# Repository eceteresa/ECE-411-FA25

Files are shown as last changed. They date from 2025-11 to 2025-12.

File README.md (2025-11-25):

# ECE 411 Fall 2025 Capstone
Hi hello! Welcome to our capstone. Please review software tools used and some tutorials for how to use said tools. :D

## Tools!

Here are the basic programs you'll need to have on your computer in order to interface with the projects:

- [VSCode](https://code.visualstudio.com/download): A helpful all-in-one programming IDE. Free!
      - You can install the [PlatformIO](https://docs.platformio.org/en/latest/integration/ide/vscode.html) extension and code .ino directly into the IDE!
- [Arduino IDE](https://www.arduino.cc/en/software/): If you would rather not use VSCode.
- Github: Not required, but _strongly_ recommended for ease of file sharing between machines. You can even work from your repo within VSCode using git bash!

### Github Onboarding Crash Course

[Github Setup](https://docs.github.com/en/get-started/git-basics/set-up-git)

[Using Git Graphical User Interface (GUI)](https://www.geeksforgeeks.org/git/working-on-git-for-gui/)

[Github markdown text cheat sheet](https://docs.github.com/en/get-started/writing-on-github/getting-started-with-writing-and-formatting-on-github/basic-writing-and-formatting-syntax)

[What are Git branches and why are they important](https://git-scm.com/book/en/v2/Git-Branching-Branches-in-a-Nutshell)

### Github Task Tracker

[Git Project Tracker Tutorial](https://docs.github.com/en/issues/planning-and-tracking-with-projects/learning-about-projects/quickstart-for-projects)
This tutorial should help you get familiar with how to use the task tracking board under "Projects" in the linked menu up above. There is a kanban template available, so it mimics what Trello can do almost exactly, if not better. The table layout was used so that it's a little easier to see who is assigned to what, and as I (Teresa) poke around with the task tracker it should be pretty intuitive to assign tasks and whatnot. And we don't have to worry about the Trello contributor limit for free accounts.

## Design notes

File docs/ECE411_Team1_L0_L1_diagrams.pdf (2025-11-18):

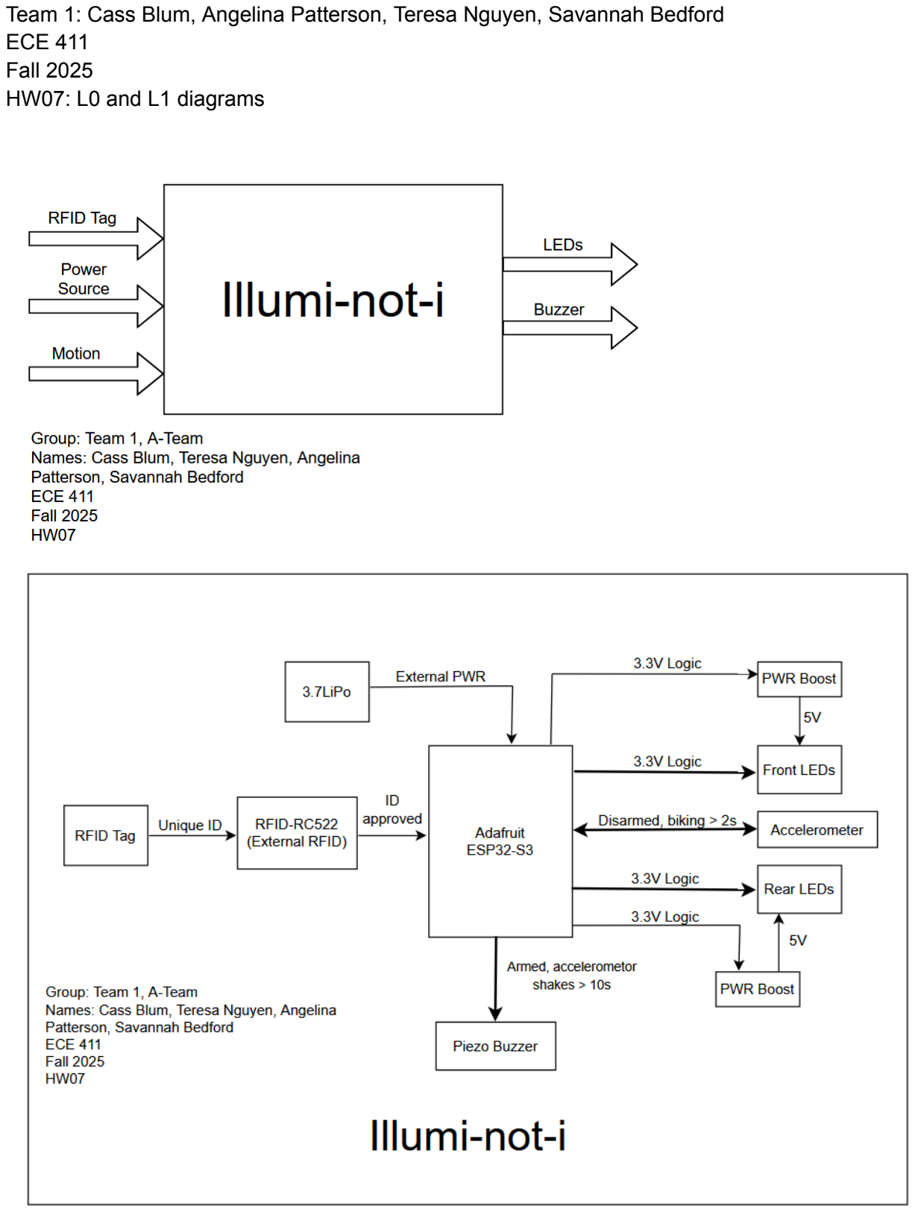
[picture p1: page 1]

Team 1: Cass Blum, Angelina Patterson, Teresa Nguyen, Savannah Bedford ECE 411
Fall 2025
HW07: L0 and L1 diagrams

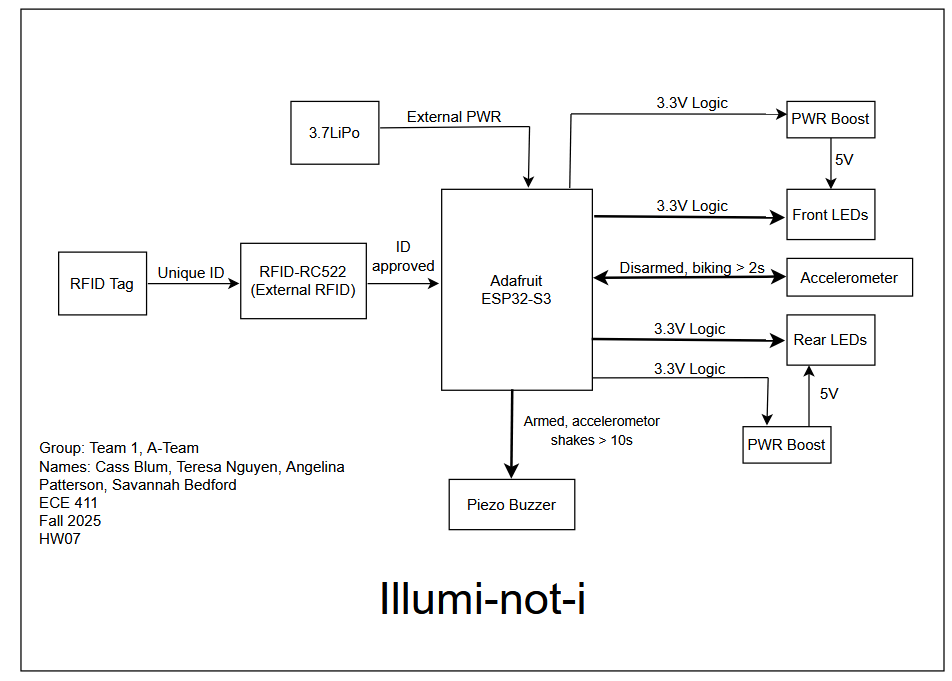
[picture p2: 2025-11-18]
docs/ECE411_Team1_HW07L1.png

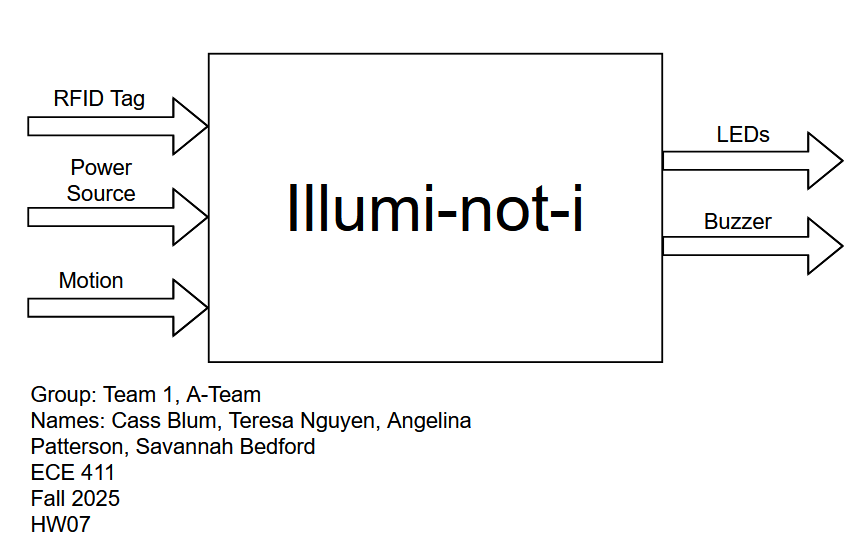
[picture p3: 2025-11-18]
docs/ECE411_Team1_HW07L0.png

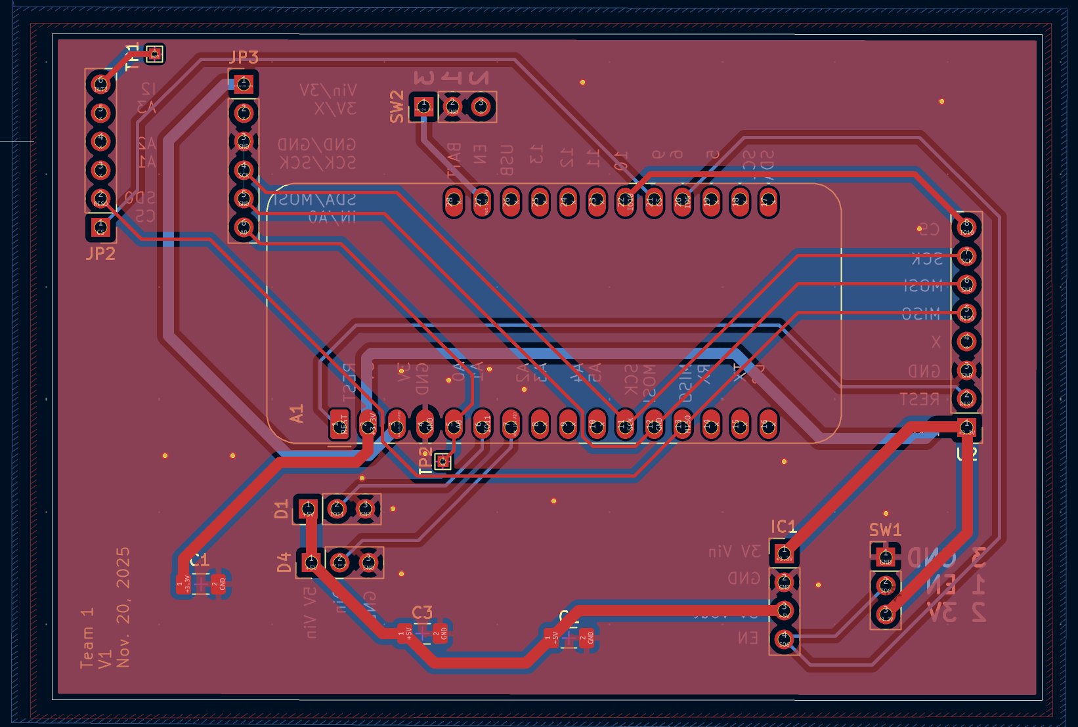
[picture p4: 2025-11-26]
docs/HW10_slideshow_images/PCB_ATeam.png

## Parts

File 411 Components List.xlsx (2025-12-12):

Component | Qty | Link | Item Price | Item Subtotal | Data Sheet | Input Voltage | Input Current | Tolerance | Notes | Subtotal | $274.13
3-axis accelerator | 4 | Adafruit (https://www.adafruit.com/product/2809) | $4.50 | $18.00 | Link (https://learn.adafruit.com/adafruit-lis3dh-triple-axis-accelerometer-breakout/downloads) | 3.3V - 5V | 130uA
WWZMDib RC522 RFID reader/writer | 4 | Amazon (https://www.amazon.com/WWZMDiB-2Pcs-RFID-Kit-Raspberry/dp/B0BDF6JT7M/ref=sr_1_3) | $6.99 | $27.96 | Link (https://www.handsontec.com/dataspecs/RC522.pdf) | 2.5V - 3.3V | 13 - 26mA |  | Tutorial (https://randomnerdtutorials.com/esp32-mfrc522-rfid-reader-arduino/) | MFRC522_digikey_datasheet (https://mm.digikey.com/Volume0/opasdata/d220001/medias/docus/5531/4411_CN0090%20other%20related%20document%20%281%29.pdf)
Adafruit Feather ESP32-S3 | 4 | Adafruit (https://learn.adafruit.com/adafruit-esp32-s3-feather/pinouts) | $17.50 | $70.00 | Link (https://learn.adafruit.com/adafruit-esp32-s3-feather) | 3.7V | 250mAh |  | Link has great overview
LiPo Battery for Feather (3.7V) | 4 | Adafruit (https://www.adafruit.com/product/3898) | $6.95 | $27.80 | Link (https://cdn-shop.adafruit.com/product-files/3898/3898_specsheet_LP801735_400mAh_3.7V_20161129.pdf) | 3.7V | 400mAh
Neopixel LED strips | 30 | Adafruit (https://www.adafruit.com/product/2552) | $2.50 | $75.00 | Link (https://cdn-shop.adafruit.com/product-files/2552/Datasheet.pdf) | 5V | 60mA |  | Needs to be powered with 5V, can handle 3.3V logic
TPS61023 Boost Converter | 5 | Adafruit (https://www.adafruit.com/product/4654) | $3.95 | $19.75 | TPS61023 chip (https://www.ti.com/product/TPS61023) | 2V - 5V -> 5V | varies |  | Boost Converter Datasheet (https://cdn-shop.adafruit.com/product-files/2552/Datasheet.pdf)
Jumper Wires | 2 | Adafruit (https://www.adafruit.com/product/1957) | $1.95 | $3.90 | n/a |  |  |  | bundle of 20
Small Breadboard | 1 | Amazon (https://www.amazon.com/DEYUE-breadboard-Set-Prototype-Board/dp/B07LFD4LT6?s=electronics) | $6.48 | $6.48 | n/a |  |  |  | pack of 6
switch | 6 | Adafruit (https://www.adafruit.com/product/805) | $0.95 | $5.70 | - | - | - | -
single row female pin headers | 3 | EPL | $1.00 | $3.00
22AWG stranded wire | 18 | EPL | $0.25 | $4.50
330 ohm resistors | 4 | EPL | $0.10 | $0.40
passive buzzers | 4 | EPL | $0.50 | $2.00
FDM Print (Protoboard Housing) | 1 | EPL | $9.64 | $9.64 | n/a | n/a | n/a | n/a | housing for protoboard

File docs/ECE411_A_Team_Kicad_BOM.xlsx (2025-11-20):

Bill Of Materials for: Team 1 - A-Team
Last modified: 11/16/2025
PCB version: 6
BOM revision: 4
Qty | Reference | Description | MF | Part number | Cost Ea. | Cost Total
1 | C1 | 10 µF ±5% 25V Ceramic Capacitor X7R 1206 (3216 Metric) | Digikey | 399-15735-2-ND | $1.39 | $1.39
2 | C2,C3 | Multilayer Ceramic Capacitors MLCC - SMD/SMT 10V 22uF X7R 1206 20 % | Mouser | 581-KGM31AR71A226MU | $0.54 | $1.08
2 | D1,D2 | RGB LED with integrated controller, 2.0 x 2.0 mm, 12 mA | Adafruit | 2552 | $3.00 | $3.00
1 | IC1 | mini-booster! Input 2-5VDC on one side | Adafruit | 4654 | $3.95 | $3.95
1 | A1 | RF Module, ESP32-S3 SoC, Wi-Fi 802.11b/g/n, Bluetooth, BLE, 32-bit, 3.3V, onboard antenna, SMD | Adafruit | 5477 | $17.50 | $17.50
1 | U2 | 3-Axis Accelerometer, 2/4/8/16g range, I2C/SPI interface, LGA-16 | Adafruit | 2809 | $4.50 | $4.50
1 | U3 | RFID RC522 Reader IC Card Module Tags SPI Interface Read and Write | YKS | CEG006900 | $6.99 | $6.99
1 | SW1 | Switch slide, single pole double throw | Adafruit | 805 | $0.95 | $0.95
VERSION INFO
Rev | Date
1 | 2025-11-07
2 | 2025-11-10
3 | 2025-11-11
3 | 2025-11-16
4 | 2025-11-20

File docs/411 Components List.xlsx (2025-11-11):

Component | Qty | Link | Item Subtotal | Data Sheet | Input Voltage | Input Current | Notes | Subtotal | $185.76
3-axis accelerator | 4 | Link (https://www.adafruit.com/product/2809) | $18.00 | Link (https://learn.adafruit.com/adafruit-lis3dh-triple-axis-accelerometer-breakout/downloads) | 3.3V - 5V | 130uA
WWZMDib RC522 RFID reader/writer | 4 | Link (https://www.amazon.com/WWZMDiB-2Pcs-RFID-Kit-Raspberry/dp/B0BDF6JT7M/ref=sr_1_3) | $27.96 | Link (https://www.handsontec.com/dataspecs/RC522.pdf) | 2.5V - 3.3V | 13 - 26mA | Tutorial (https://randomnerdtutorials.com/esp32-mfrc522-rfid-reader-arduino/) | MFRC522_digikey_datasheet (https://mm.digikey.com/Volume0/opasdata/d220001/medias/docus/5531/4411_CN0090%20other%20related%20document%20%281%29.pdf)
Adafruit Feather ESP32-S3 | 4 | Adafruit (https://www.adafruit.com/product/5000) | $27.96 | Link (https://learn.adafruit.com/adafruit-esp32-s3-feather) | 3.7V | 250mAh | Link has great overview
LiPo Battery for Feather (3.7V) | 4 | Link (https://www.adafruit.com/product/3898) | $27.96 | Link (https://cdn-shop.adafruit.com/product-files/3898/3898_specsheet_LP801735_400mAh_3.7V_20161129.pdf) | 3.7V | 400mAh
Neopixel LED strips | 8 | Adafruit (https://www.adafruit.com/product/2552) | $55.92
TPS61023 Boost Converter | 4 | Adafruit (https://www.adafruit.com/product/4654) | $27.96 | TPS61023 chip (https://www.ti.com/product/TPS61023) | 2V - 5V -> 5V | varies | Boost Converter Datasheet (https://cdn-shop.adafruit.com/product-files/2552/Datasheet.pdf)

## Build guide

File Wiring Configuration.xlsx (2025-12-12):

Component | ESP32 | LIS3DH | RFID | LED 1 | LED 2 | TPS | PIEZO
Pin Number | 5 |  |  | Din
 | 6 |  |  |  | Din
 | 9 | CS
 | 10 |  | SDA
 | 11 |  |  |  |  |  | Terminal 1
 | 5 to LED
 | RST |  | RST
 | 3.3V | Vin | 3.3V |  |  | Vin
 | GND | GND | GND | GND | GND | GND | GND
 | A0 | INT
 | SCK | SCL | SCK
 | MO | SDA | MOSI
 | MI | SDO | MI
 |  |  |  | 5V | 5V | 5V

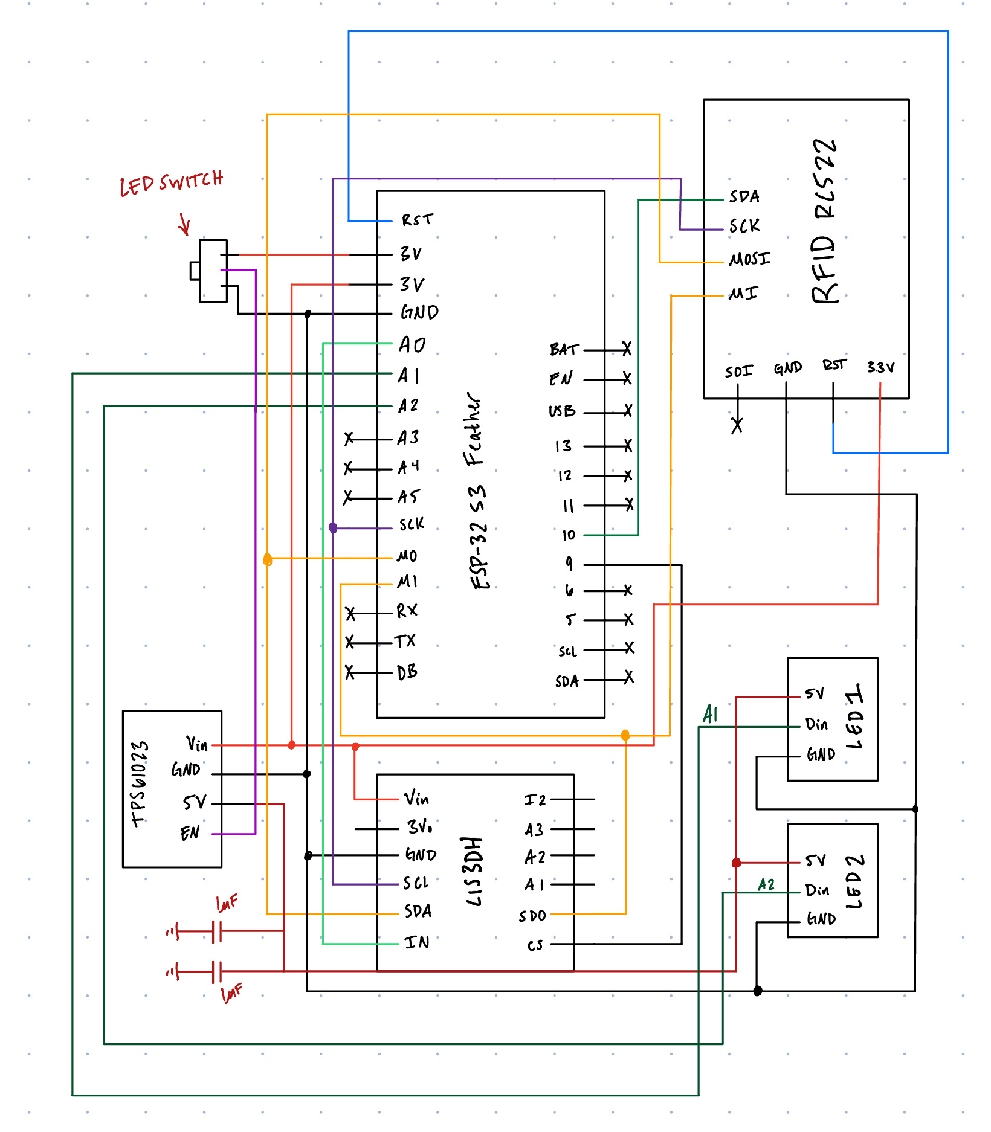
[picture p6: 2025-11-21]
docs/411wiringDiagram_rev2.png

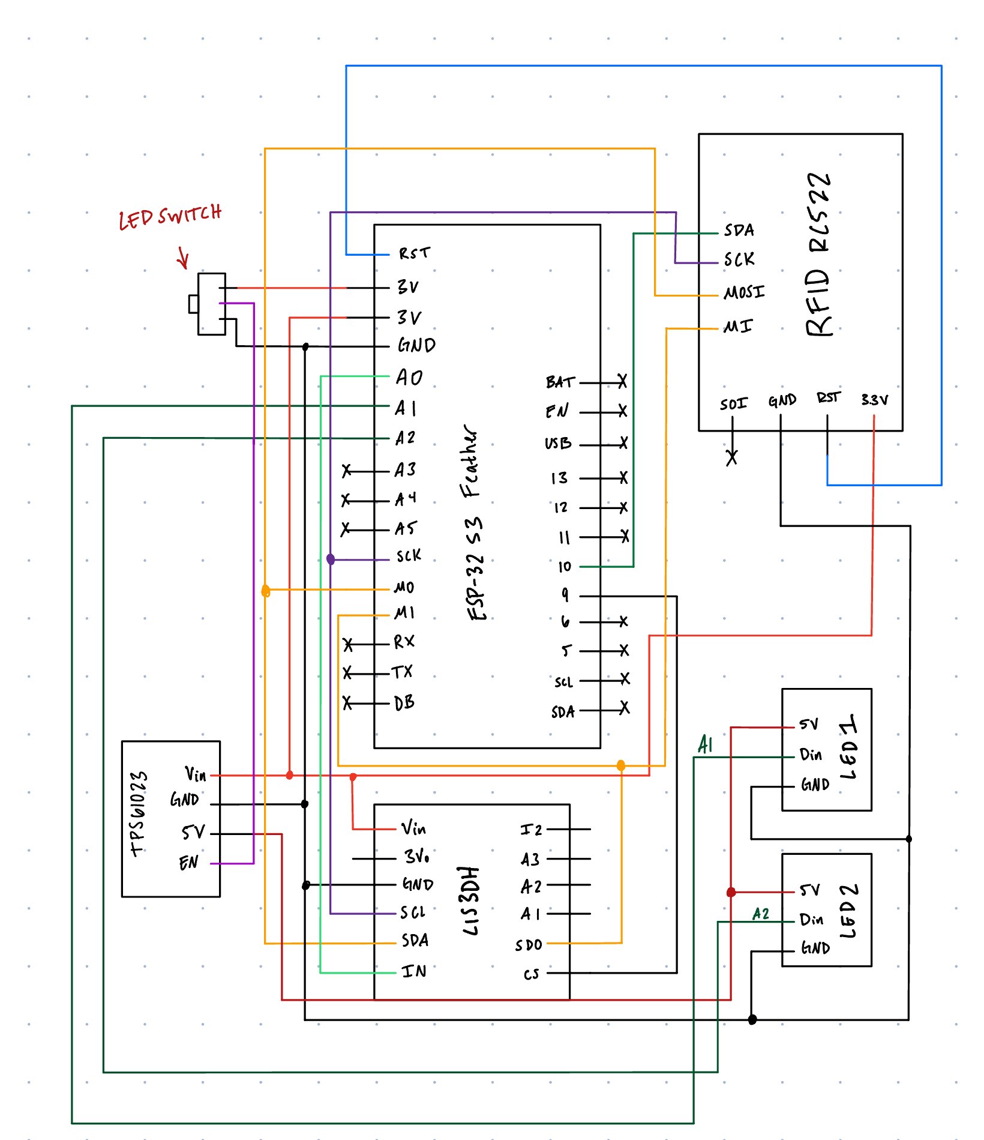
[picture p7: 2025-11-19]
docs/411wiringDiagram.jpg

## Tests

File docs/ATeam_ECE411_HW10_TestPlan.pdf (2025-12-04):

Test Case

Test Author: A-Team (Cass Blum, Teresa Nguyen, Savannah Bedford, Angelina Patterson)
Test Case Name: | Illumi-not-i full system test | Test ID #: | Illumi-not-i-01
Description: | Testing our subsystems that feature the RFID arming and disarming of the alarm system, checking the LiPo battery, along with the LEDs when implemented, and ensuring the accelerometer detects motion and the boost converter powers up the LED strips. | Type: | □ white box □ black box □ __Both______

Tester Information
| Name of Tester: | | Date:
| HW/SW Version: | 1.0 | Time:
| Setup: | Ensure the system's features are fully integrated.
S T E P | Action | Expected Result | P A S S | F A I L | N / A | Comments
1 | 3.7V LiPol battery | -The ESP32-S3 powers on along with the LED strips.
2 | Accelerometer | - Timed shaker testing: - >10s, serial monitor reads “Stealing!” - <10s, serial monitor reads, “10s alarm timer set…” - >2s, serial monitor reads, “Biking!” - <2s, serial monitor does nothing - >3s, serial monitor reads, “Stopped!” - <3s, serial monitor reads, “Biking!”
3 | RFID Tag | -RFID is tapped, it arms the system. - RFID badge is tapped after arming, it DISARMS the system.
4 | Piezo Buzzer | Based on the accelerometer motion: - On when shaken >10s. - Off when shaken <10s. Timer resets and continues countdown.
5 | Boost converter | -Converts 3.7V to 5V. - Powers on the LED strips.
2025-11-28 | Page 1 of 4

6 | LED strips | -LED strips are on. - The switch is flipped, and the LEDs light up. - The brightness of the LEDs is adjusted.
| Overall test result:

Matrix Test

Test Author: A-Team

Test Case Name: | LED strip behavior and power test | Test ID #: | LED-01
Description: | Verification of the LED strips lights up based on the input voltage of the boost converter. To demonstrate how the power system and LEDs behave under different supply conditions. | Type: | □ white box □ black box □ _____________

Tester Information

| Name of Tester: | | Date:
| HW/SW Version: | 1.0 | Time:
| Setup: | Isolate the LED system and use a power supply to test the input with different number values 0 - 255 based on NeoPixel’s RGB value settings
T E S T | INPUTS | EXPECTED OUTPUTS | P A S S | F A I L | N / A | Comments
1 | 255 | LEDs at max brightness.
2 | 175 | LEDs slightly dim from max brightness.
3 | 90 | LEDs start to dim or flicker
4 | 50 | LEDs are flickering or are about to turn off.

5 | 0 | LEDs should not turn on.
| Overall test result:

Test Author: A-Team

Test Case Name: | RFID badge test | Test ID #: | RFID-01
Description: | Verification of RFID badge functionality. When the RFID badge is tapped it should be able to read the dedicated hex ID, as well as determine if the Illumi-not-i system is armed or disarmed. | Type: | □ white box □ black box □ _____________

Tester Information

| Name of Tester: | Teresa Nguyen | Date: | 05-12-2025
| HW/SW Version: | 1.0 | Time: | Is fake
| Setup: | Testing RFID functionality
T E S T | INPUTS | EXPECTED OUTPUTS | P A S S | F A I L | N / A | Comments
1 | RFID ID recognition | Serial Monitor gives approval message if correct badge, rejection message if incorrect badge.
2 | RFID arming the system | If Illumi-not-i is ARMED, serial monitor should read “locked!” when RFID badge taps. If time, add RFID lighting system to reflect behavior (flash red? orange?)

3 | RFID disarming the system | If Illumi-not-i is DISARMED, serial monitor should read “unlocked!” when RFID badge taps. If time, add RFID lighting system to reflect behavior (flash green? purple?)
| Overall test result:

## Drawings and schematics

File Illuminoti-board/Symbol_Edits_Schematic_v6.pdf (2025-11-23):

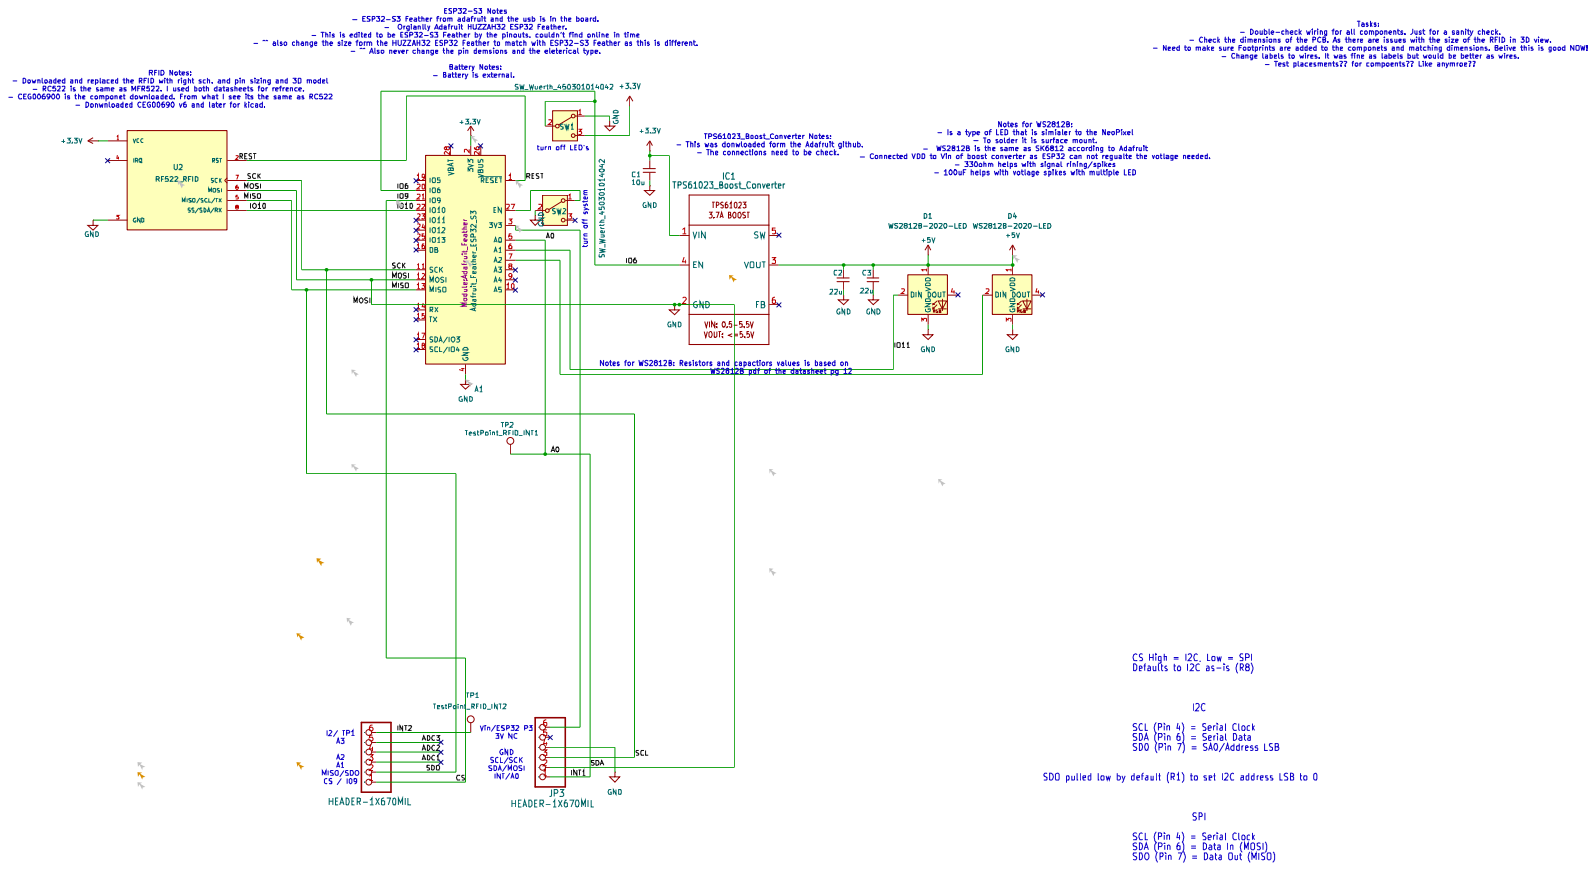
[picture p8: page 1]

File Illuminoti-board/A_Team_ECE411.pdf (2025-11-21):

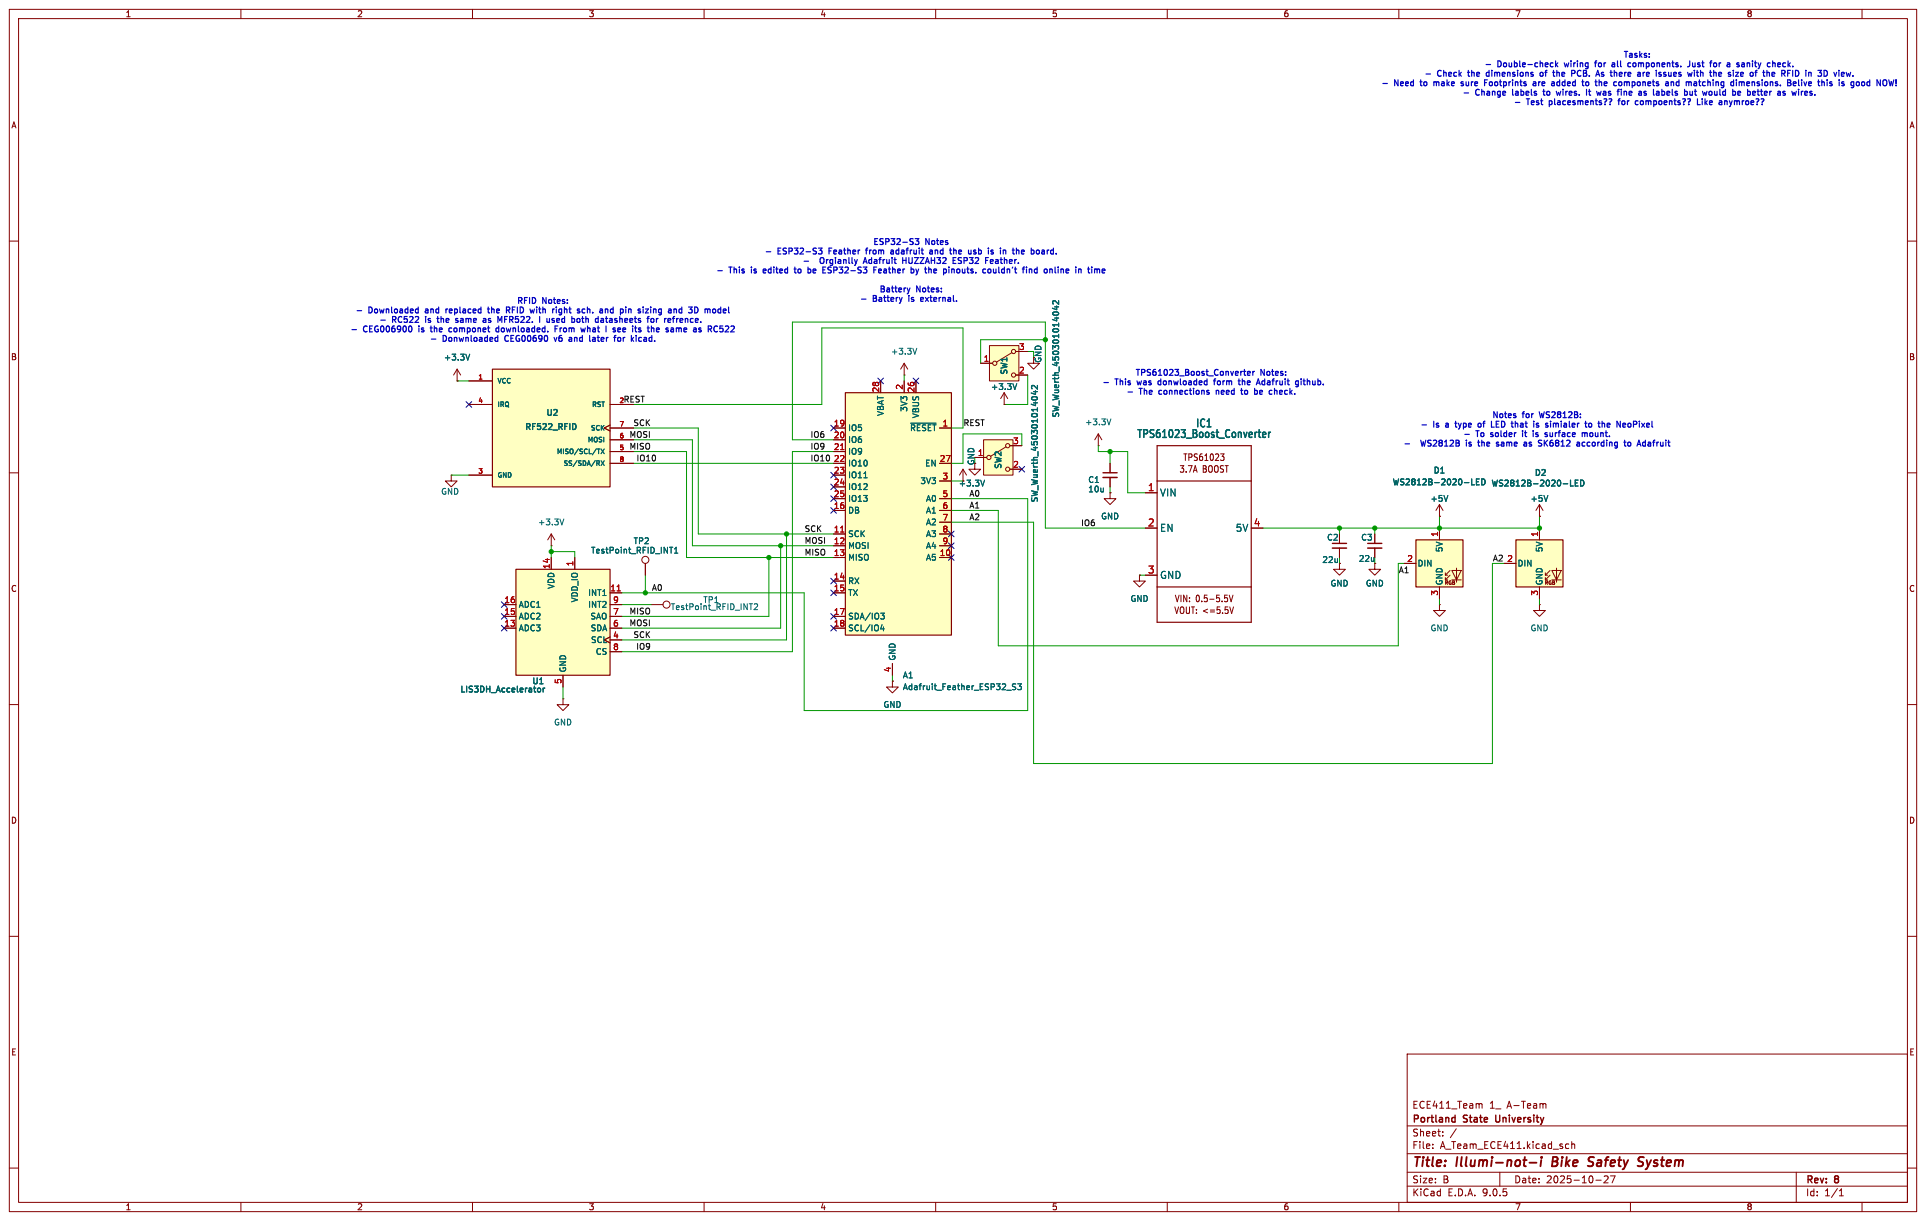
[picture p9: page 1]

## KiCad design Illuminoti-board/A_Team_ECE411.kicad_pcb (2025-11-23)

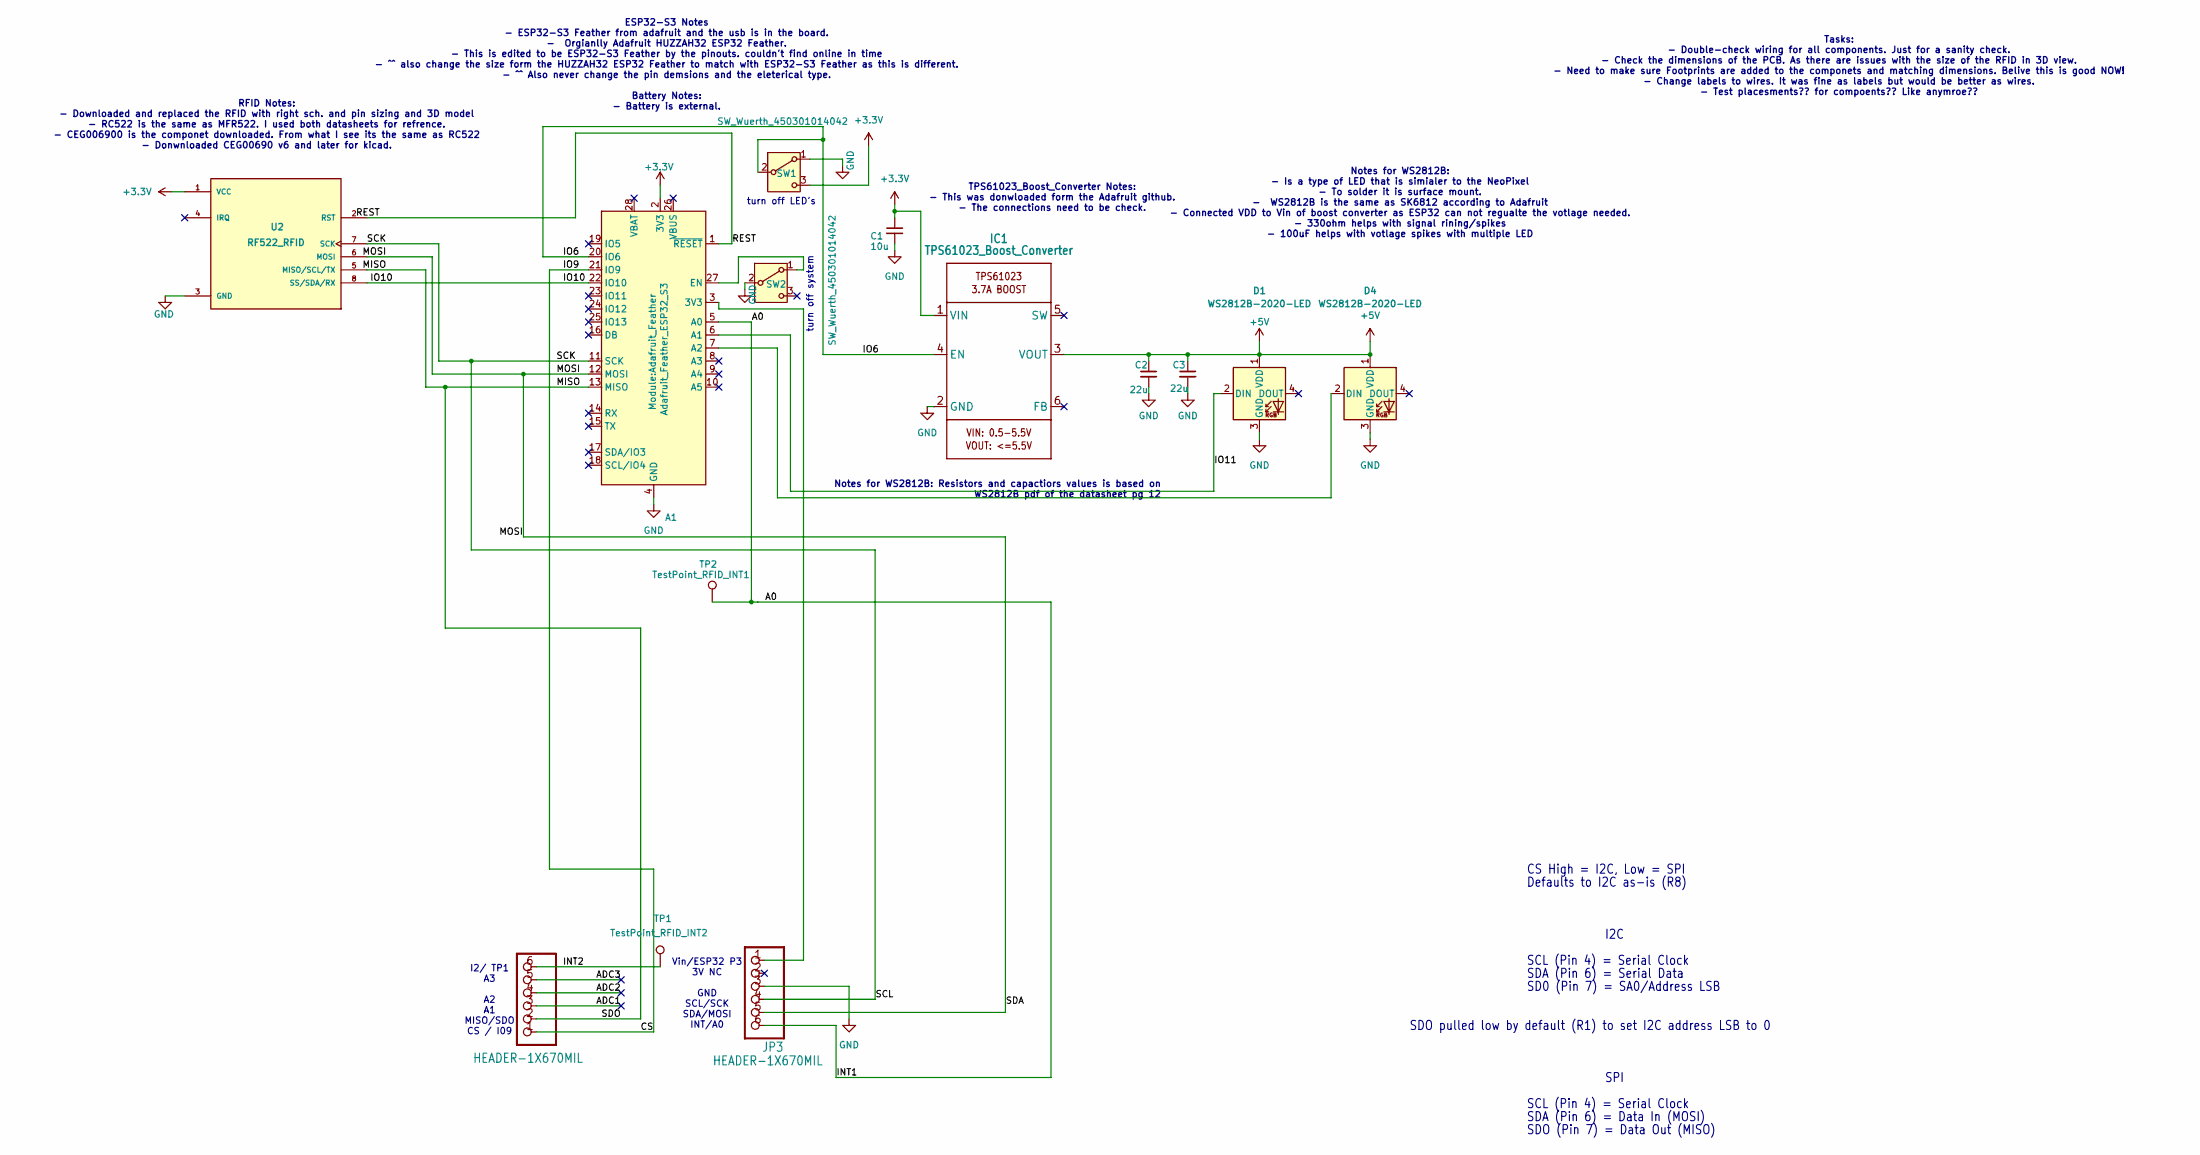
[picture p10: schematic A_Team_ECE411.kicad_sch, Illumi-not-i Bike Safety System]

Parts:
A1: Adafruit_Feather_ESP32_S3; Adafruit_Feather
C1: 10u; C_1206_3216Metric_Pad1.33x1.80mm_HandSolder; Part number 399-15735-2-ND
C2, C3: 22u; C_1206_3216Metric_Pad1.33x1.80mm_HandSolder; Part number 581-KGM31AR71A226MU
D1, D4: WS2812B-2020-LED; PinHeader_1x03_P2.54mm_Vertical; Part number 2552
IC1: TPS61023_Boost_Converter; PinHeader_1x04_P2.54mm_Vertical; Part number 4654
JP2, JP3: HEADER-1X670MIL; PinHeader_1x06_P2.54mm_Vertical
SW1, SW2: SW_Wuerth_450301014042; PinHeader_1x03_P2.54mm_Vertical
TP1: TestPoint_RFID_INT2; TestPoint_THTPad_1.0x1.0mm_Drill0.5mm
TP2: TestPoint_RFID_INT1; TestPoint_THTPad_1.0x1.0mm_Drill0.5mm
U2: RF522_RFID; PinHeader_1x08_P2.54mm_Vertical; PARTREV 12 June 2019

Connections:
+3.3V: A1.2 (3V3), C1.1, IC1.1 (VIN), SW1.3 (3V), U2.1 (VCC)
+5V: C2.1, C3.1, D1.1 (VDD), D4.1 (VDD), IC1.3 (VOUT)
/A0: A1.5 (A0), JP3.6, TP2.1
/ADC1: JP2.3
/ADC2: JP2.4
/ADC3: JP2.5
/CS: A1.21 (IO9), JP2.1
/INT2: JP2.6, TP1.1
/IO6: A1.20 (IO6), IC1.4 (EN), SW1.2 (B)
/IO10: A1.22 (IO10), U2.8 (SS/SDA/RX)
/IO11: A1.6 (A1), D1.2 (DIN)
/MISO: A1.13 (MISO), JP2.2, U2.5 (MISO/SCL/TX)
/MOSI: A1.12 (MOSI), JP3.5, U2.6 (MOSI)
/REST: A1.1 (~RESET), U2.2 (RST)
/SCK: A1.11 (SCK), JP3.4, U2.7 (SCK)
GND: A1.4 (GND), C1.2, C2.2, C3.2, D1.3 (GND), D4.3 (GND), IC1.2 (GND), JP3.3, SW1.1 (GND), SW2.2 (B), U2.3 (GND)
unnamed: A1.3 (3V3), JP3.1
unnamed: A1.7 (A2), D4.2 (DIN)
unnamed: A1.27 (EN), SW2.1 (A)

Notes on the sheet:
Tasks: - Double-check wiring for all components. Just for a sanity check. - Check the dimensions of the PCB. As there are issues with the size of the RFID in 3D view. - Need to make sure Footprints are added to the componets and matching dimensions. Belive this is good NOW! - Change labels to wires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
SDO (Pin 7) = Data Out (MISO)
SDA (Pin 6) = Data In (MOSI)
SCL (Pin 4) = Serial Clock
I2/ TP1 A3 A2 A1 MISO/SDO CS / I09
SPI
SD0 (Pin 7) = SA0/Address LSB
ESP32-S3 Notes - ESP32-S3 Feather from adafruit and the usb is in the board. - Orgianlly Adafruit HUZZAH32 ESP32 Feather. - This is edited to be ESP32-S3 Feather by the pinouts. couldn't find online in time - ^^ also change the size form the HUZZAH32 ESP32 Feather to match with ESP32-S3 Feather as 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
SDO pulled low by default (R1) to set I2C address LSB to 0
TPS61023_Boost_Converter Notes: - This was donwloaded form the Adafruit github. - The connections need to be check.
Notes for WS2812B: - Is a type of LED that is simialer to the NeoPixel - To solder it is surface mount. - WS2812B is the same as SK6812 according to Adafruit - Connected VDD to Vin of boost converter as ESP32 can not regualte the votlage needed. - 330ohm helps with signal rining/spikes - 100uF help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
Vin/ESP32 P3 3V NC GND SCL/SCK SDA/MOSI INT/A0
Defaults to I2C as-is (R8)
SDA (Pin 6) = Serial Data
turn off LED's
turn off system
Notes for WS2812B: Resistors and capactiors values is based on WS2812B pdf of the datasheet pg 12
CS High = I2C, Low = SPI
RFID Notes: - Downloaded and replaced the RFID with right sch. and pin sizing and 3D model - RC522 is the same as MFR522. I used both datasheets for refrence. - CEG006900 is the componet downloaded. From what I see its the same as RC522 - Donwnloaded CEG00690 v6 and later for kicad.
I2C

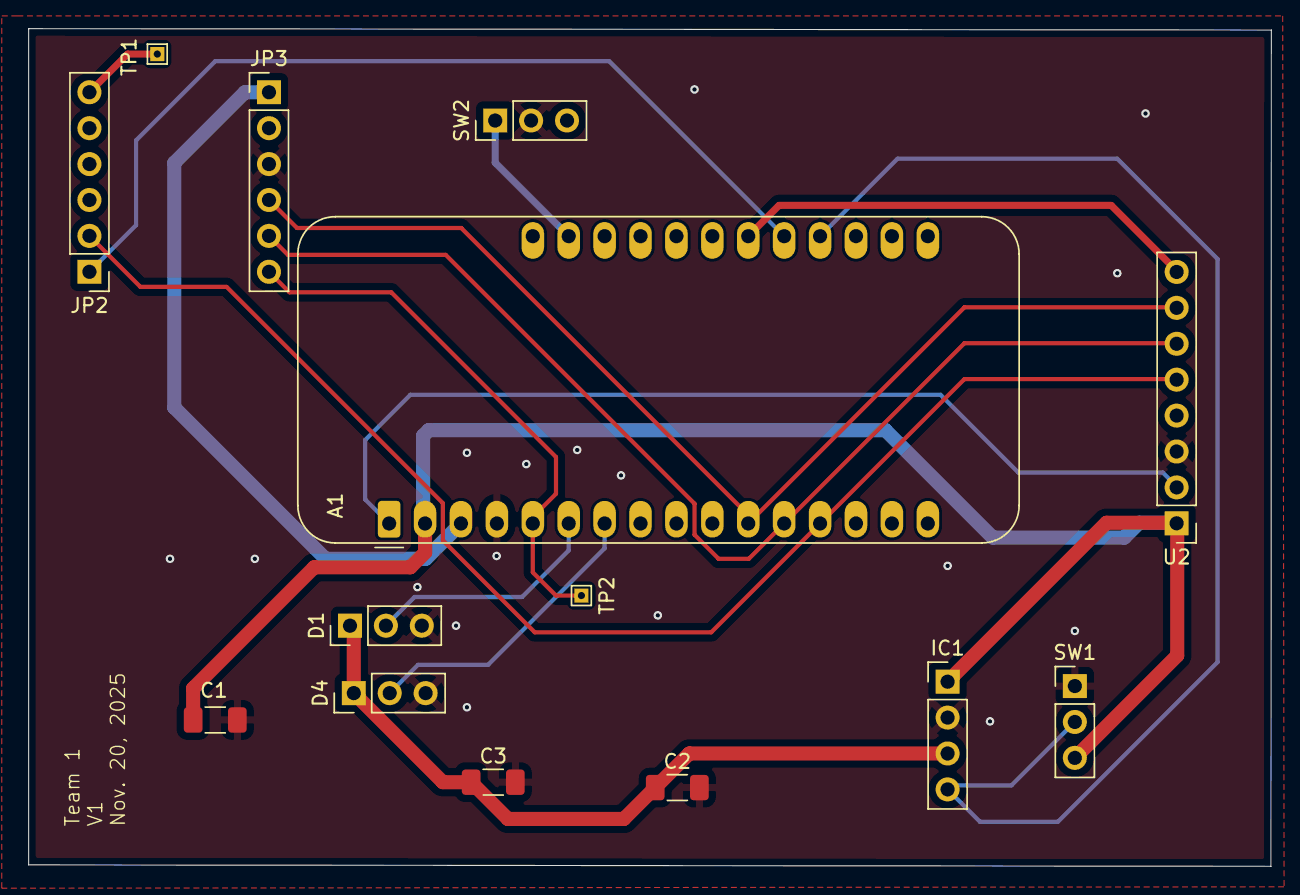
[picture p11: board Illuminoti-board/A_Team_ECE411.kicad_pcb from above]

Board: 2 copper layers, 87.9 x 59.2 mm, 14 parts (0 on the bottom side), 16 nets.

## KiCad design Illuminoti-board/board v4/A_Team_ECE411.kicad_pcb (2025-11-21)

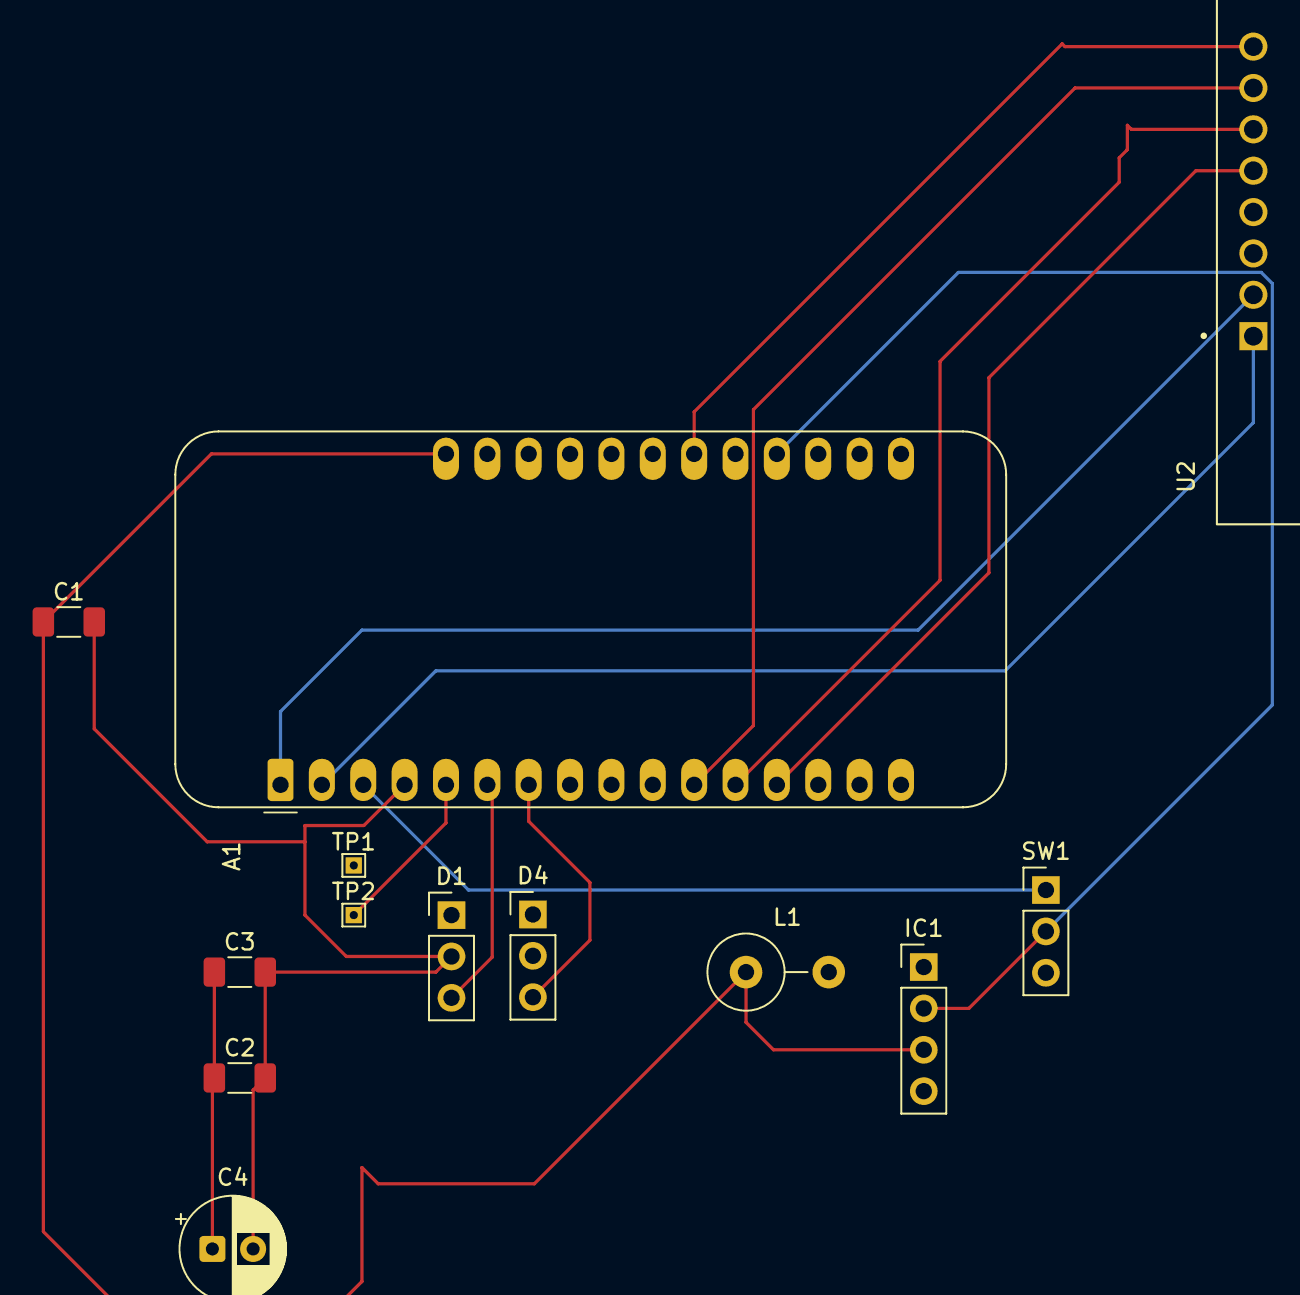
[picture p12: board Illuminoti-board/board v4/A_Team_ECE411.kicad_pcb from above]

Board: 2 copper layers, 13 parts (0 on the bottom side), 14 nets.

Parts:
A1: Adafruit_Feather_ESP32_S3; Adafruit_Feather
C1: 10u; C_1206_3216Metric_Pad1.33x1.80mm_HandSolder
C2, C3: 22u; C_1206_3216Metric_Pad1.33x1.80mm_HandSolder
C4: 100u; CP_Radial_D6.3mm_P2.50mm
D1, D4: WS2812B-2020-LED; PinHeader_1x03_P2.54mm_Vertical
IC1: TPS61023_Boost_Converter; PinHeader_1x04_P2.54mm_Vertical
L1: 1u; L_Axial_L11.0mm_D4.5mm_P5.08mm_Vertical_Fastron_MECC
SW1: SW_Wuerth_450301014042; PinHeader_1x03_P2.54mm_Vertical
TP1: TestPoint_RFID_INT2; TestPoint_THTPad_1.0x1.0mm_Drill0.5mm
TP2: TestPoint_RFID_INT1; TestPoint_THTPad_1.0x1.0mm_Drill0.5mm
U2: RF522_RFID; MODULE_CEG006900

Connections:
+3.3V: A1.2 (3V3), U2.1 (VCC)
+5V: C2.1, C3.1, C4.1
+BATT: A1.28 (VBAT), C1.1, IC1.3 (VIN), L1.1
/A0: A1.5 (A0), TP2.1
/IO6: A1.20 (IO6), IC1.2 (EN), SW1.2 (C)
/IO10: A1.22 (IO10), U2.8 (SS/SDA/RX)
/IO11: A1.6 (A1), D1.3 (DIN)
/MISO: A1.13 (MISO), U2.5 (MISO/SCL/TX)
/MOSI: A1.12 (MOSI), U2.6 (MOSI)
/REST: A1.1 (~RESET), U2.2 (RST)
/SCK: A1.11 (SCK), U2.7 (SCK)
GND: A1.4 (GND), C1.2, C2.2, C3.2, C4.2, D1.2 (VSS), D4.2 (VSS), IC1.4 (GND), SW1.3 (A), U2.3 (GND)
unnamed: A1.7 (A2), D4.3 (DIN)
unnamed: A1.3 (3V3), SW1.1 (B)

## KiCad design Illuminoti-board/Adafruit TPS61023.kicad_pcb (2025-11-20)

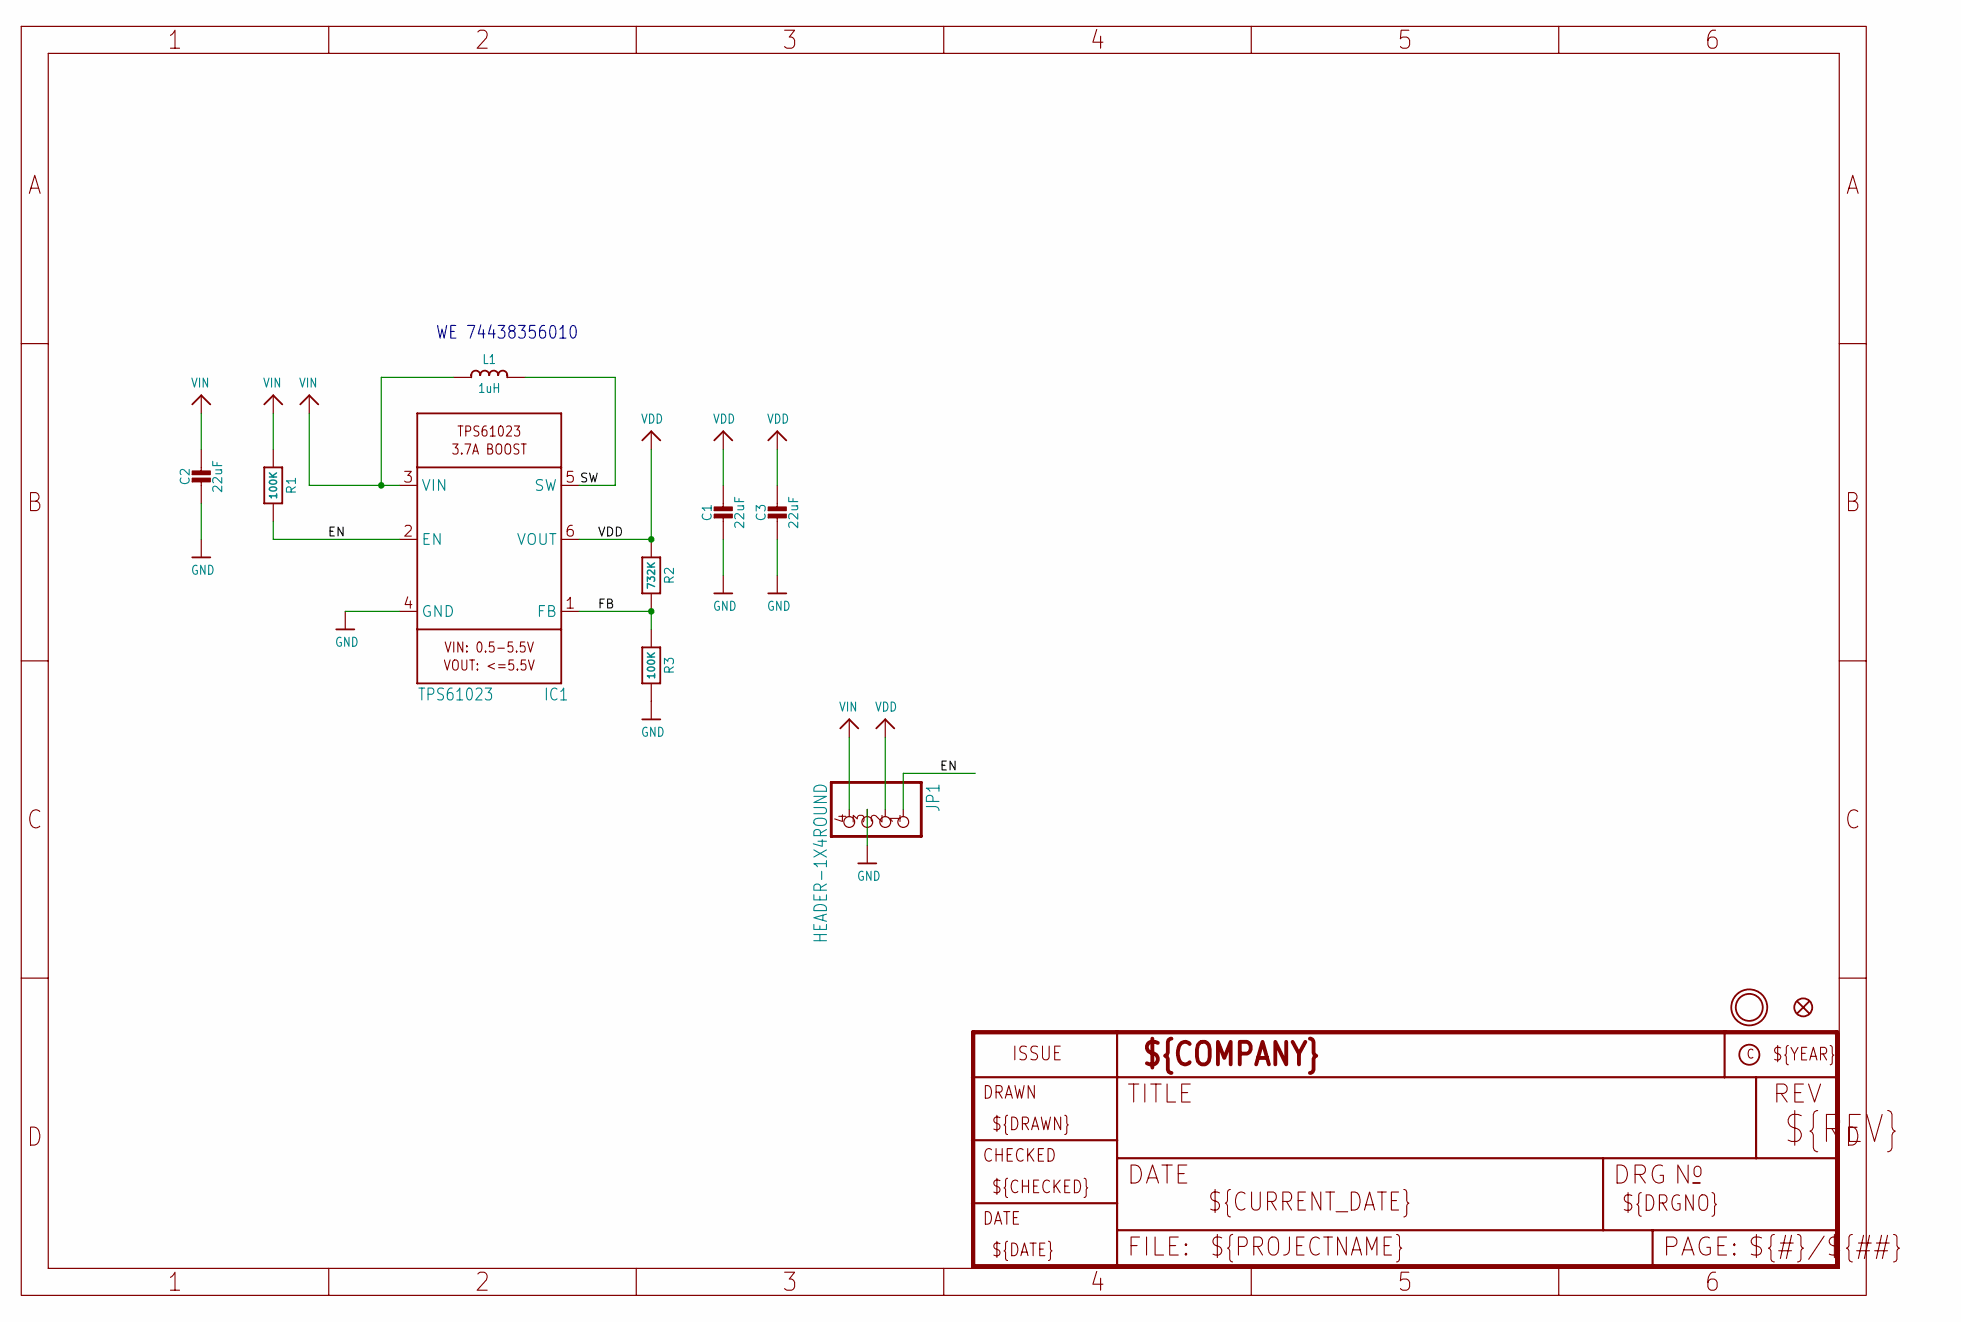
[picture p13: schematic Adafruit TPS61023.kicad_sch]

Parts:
C1, C2, C3: 22uF; 0805-NO
FID1: FIDUCIAL_1MM
IC1: TPS61023; SOT563
JP1: HEADER-1X4ROUND; 1X04_ROUND
L1: 1uH; INDUCTOR_5X5MM_TDK_VLC5045
R1, R3: 100K; 0603-NO
R2: 732K; 0603-NO
U$9: MOUNTINGHOLE2.5; MOUNTINGHOLE_2.5_PLATED

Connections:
EN: IC1.2 (EN), JP1.1, R1.2
FB: IC1.1 (FB), R2.2, R3.1
GND: C1.2, C2.2, C3.2, IC1.4 (GND), JP1.3, R3.2
SW: IC1.5 (SW), L1.P$2 (2)
VDD: C1.1, C3.1, IC1.6 (VOUT), JP1.2, R2.1
VIN: C2.1, IC1.3 (VIN), JP1.4, L1.P$1 (1), R1.1

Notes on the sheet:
WE 74438356010

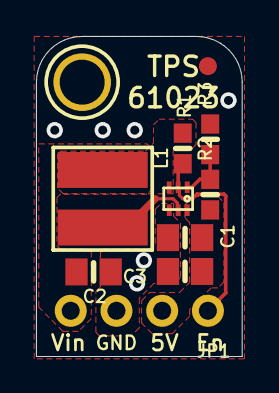
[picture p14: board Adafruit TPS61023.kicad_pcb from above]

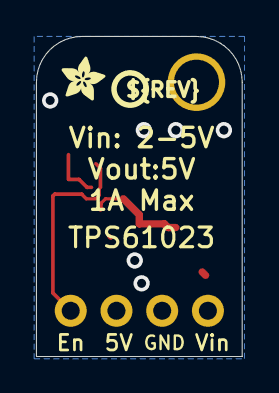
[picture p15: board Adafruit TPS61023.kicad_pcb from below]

Board: 2 copper layers, 11.4 x 17.8 mm, 13 parts (2 on the bottom side), 6 nets.

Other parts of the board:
U$10: PCBFEAT-REV-040
U$11: ADAFRUIT_2.5MM

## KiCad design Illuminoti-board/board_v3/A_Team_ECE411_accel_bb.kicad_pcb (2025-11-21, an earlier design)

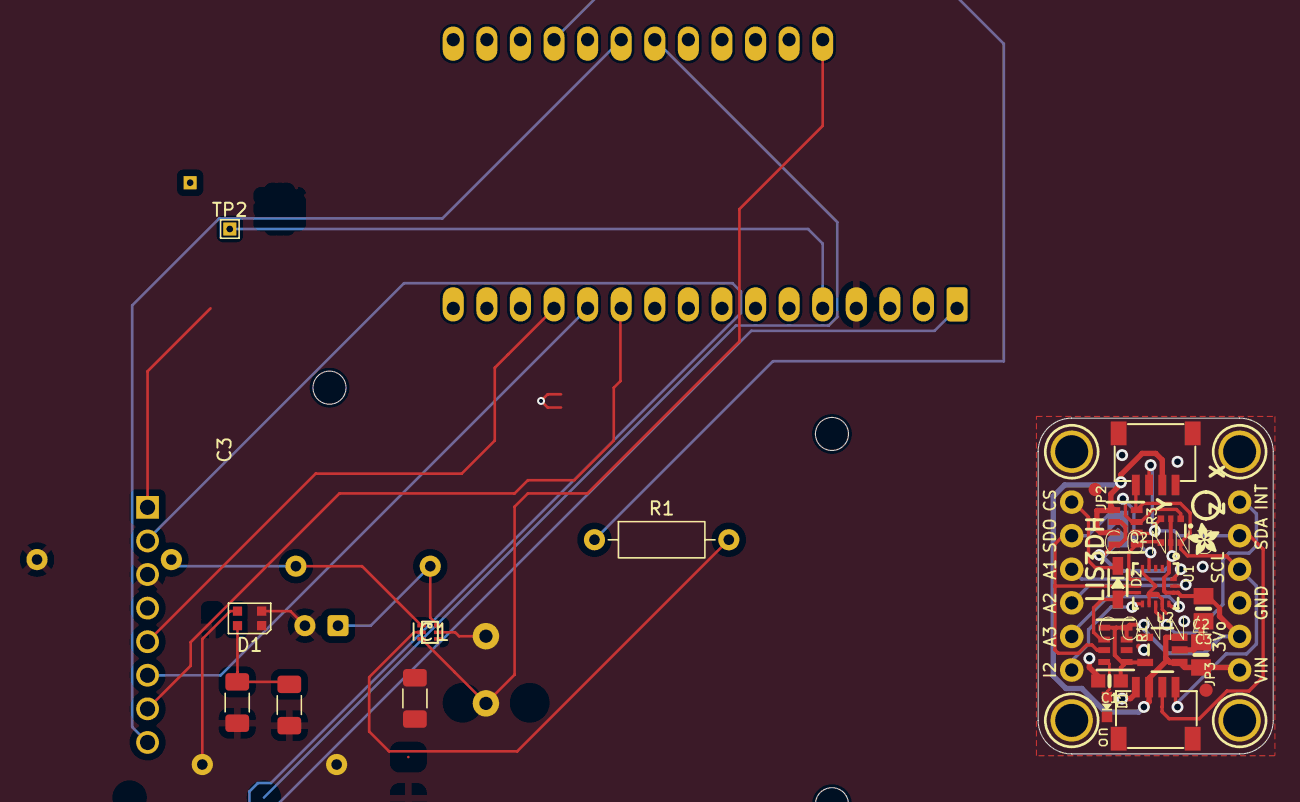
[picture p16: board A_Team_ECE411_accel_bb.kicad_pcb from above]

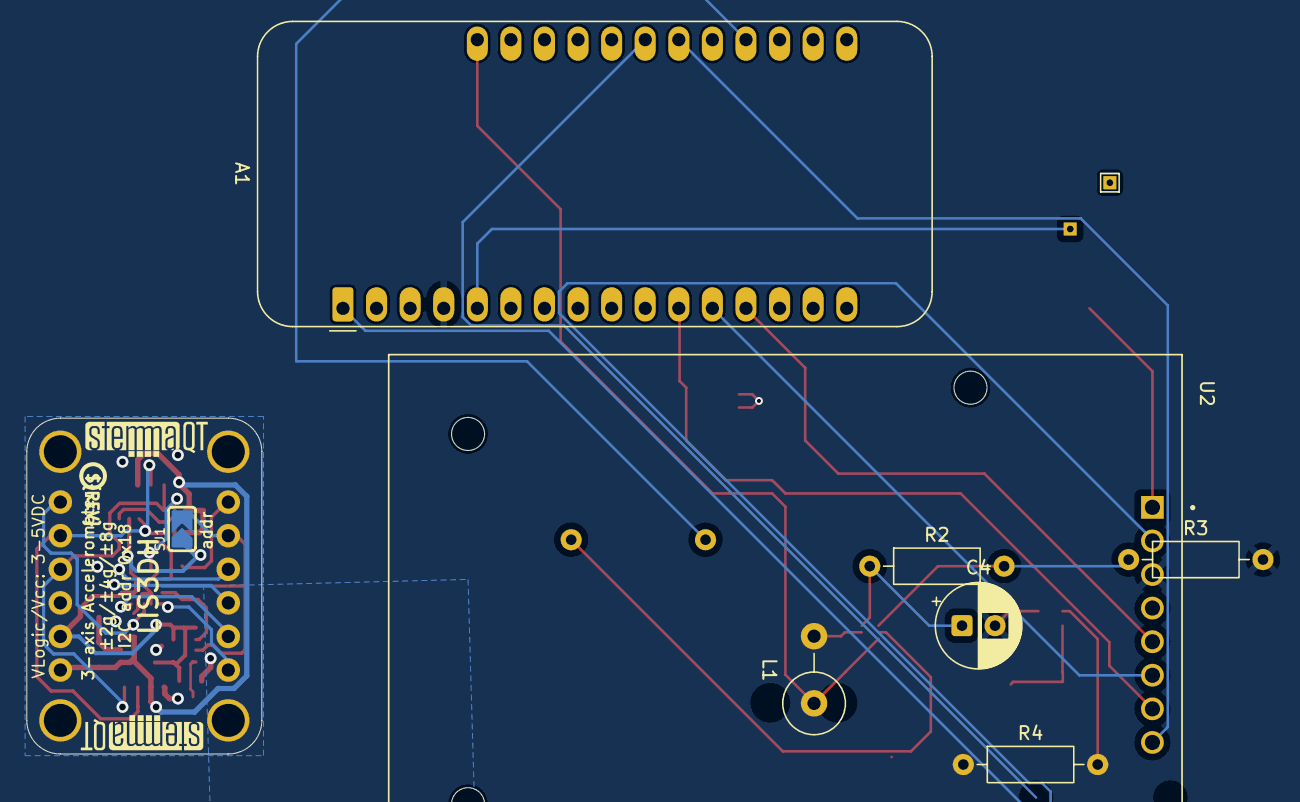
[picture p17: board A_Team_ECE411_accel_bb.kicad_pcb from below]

Board: 2 copper layers, 17.8 x 25.4 mm, 40 parts (12 on the bottom side), 31 nets.

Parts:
A1: Adafruit_Feather_ESP32_S3; Adafruit_Feather
C1: 0.1uF; 0603-NO
C1#2: 10u; C_1206_3216Metric_Pad1.33x1.80mm_HandSolder
C2, C3#2: 22u; C_1206_3216Metric_Pad1.33x1.80mm_HandSolder
C2#2, C3: 10uF; 0805-NO
C4: 100u; CP_Radial_D6.3mm_P2.50mm
CONN3, CONN4: STEMMA_I2C_QT; JST_SH4
D1: GREEN; CHIPLED_0603_NOOUTLINE
D1#2: WS2812B-2020-LED; LED_WS2812B-2020_PLCC4_2.0x2.0mm
D2: 1N4148; SOD-323
FID3, FID4: FIDUCIAL_1MM
IC1: TPS61023_Boost_Converter; SOT563
JP2, JP3: 1X06_ROUND_70
L1: 1u; L_Axial_L11.0mm_D4.5mm_P5.08mm_Vertical_Fastron_MECC
Q2: BSS138; SOT363
R1: 10k; R_Axial_DIN0207_L6.3mm_D2.5mm_P10.16mm_Horizontal
R1#2, R3: 10K; RESPACK_4X0603
R2: 723k; R_Axial_DIN0207_L6.3mm_D2.5mm_P10.16mm_Horizontal
R3#2: 100k; R_Axial_DIN0207_L6.3mm_D2.5mm_P10.16mm_Horizontal
R4: 330; R_Axial_DIN0207_L6.3mm_D2.5mm_P10.16mm_Horizontal
SJ1: SOLDERJUMPER_ARROW_NOPASTE
TP1: TestPoint_RFID_INT2; TestPoint_THTPad_1.0x1.0mm_Drill0.5mm
TP2: TestPoint_RFID_INT1; TestPoint_THTPad_1.0x1.0mm_Drill0.5mm
U1: LIS3DHTR; LGA16_3X3MM
U2: AP2112K-3.3; SOT23-5
U2#2: RF522_RFID; MODULE_CEG006900
U$1, U$17, U$19, U$21: MOUNTINGHOLE2.5; MOUNTINGHOLE_2.5_PLATED
U$12: ADAFRUIT_2.5MM
U$25: PCBFEAT-REV-040
U$30, U$31: STEMMAQT

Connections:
3.3V: C1.1, C3.1, JP3.2, Q2.2, Q2.5, R1#2.1, R1#2.5, R1#2.7, R1#2.8, R3.2, R3.4, SJ1.1, U1.1, U1.14, U2.5
+3.3V: A1.2 (3V3), U2#2.1 (VCC)
+5V: C2.1, C3#2.1, C4.1, D1#2.4 (VDD), IC1.6 (VOUT), R2.1
+BATT: A1.28 (VBAT), C1#2.1, IC1.3 (VIN), L1.1
/A0: A1.5 (A0), TP2.1
/IO6: A1.20 (IO6), R1.1
/IO10: A1.22 (IO10), U2#2.8 (SS/SDA/RX)
/IO11: A1.23 (IO11), R4.1
/MISO: A1.13 (MISO), U2#2.5 (MISO/SCL/TX)
/MOSI: A1.12 (MOSI), U2#2.6 (MOSI)
/REST: A1.1 (~RESET), U2#2.2 (RST)
/SCK: A1.11 (SCK), U2#2.7 (SCK)
ADC1: JP2.3, U1.16
ADC2: JP2.4, U1.15
ADC3: JP2.5, U1.13
CS: D2.C, JP2.1
GND: A1.4 (GND), C1.2, C1#2.2, C2.2, C2#2.2, C3.2, C3#2.2, C4.2, CONN3.1, CONN4.1, D1.C, D1#2.2 (VSS), IC1.4 (GND), JP3.3, R1#2.6, R3#2.2, U1.5, U1.10, U1.12, U2.2, U2#2.3 (GND)
INT1: JP3.6, U1.11
INT2: JP2.6, U1.9
unnamed: D1.A, R1#2.4
unnamed: D2.A, R1#2.2, U1.8
unnamed: D1#2.3 (DIN), R4.2
unnamed: IC1.2 (EN), R1.2
unnamed: IC1.1 (FB), R2.2, R3#2.1
unnamed: IC1.5 (SW), L1.2
SCL: CONN3.4, CONN4.4, JP3.4, Q2.6, R3.8
SCL_3V: Q2.1, R3.7, U1.4
SDA: CONN3.3, CONN4.3, JP3.5, Q2.3, R3.6
SDA_3V: Q2.4, R3.5, U1.6
SDO: JP2.2, R1#2.3, SJ1.2, U1.7
VCC: C2#2.1, CONN3.2, CONN4.2, JP3.1, R3.1, R3.3, U2.1, U2.3

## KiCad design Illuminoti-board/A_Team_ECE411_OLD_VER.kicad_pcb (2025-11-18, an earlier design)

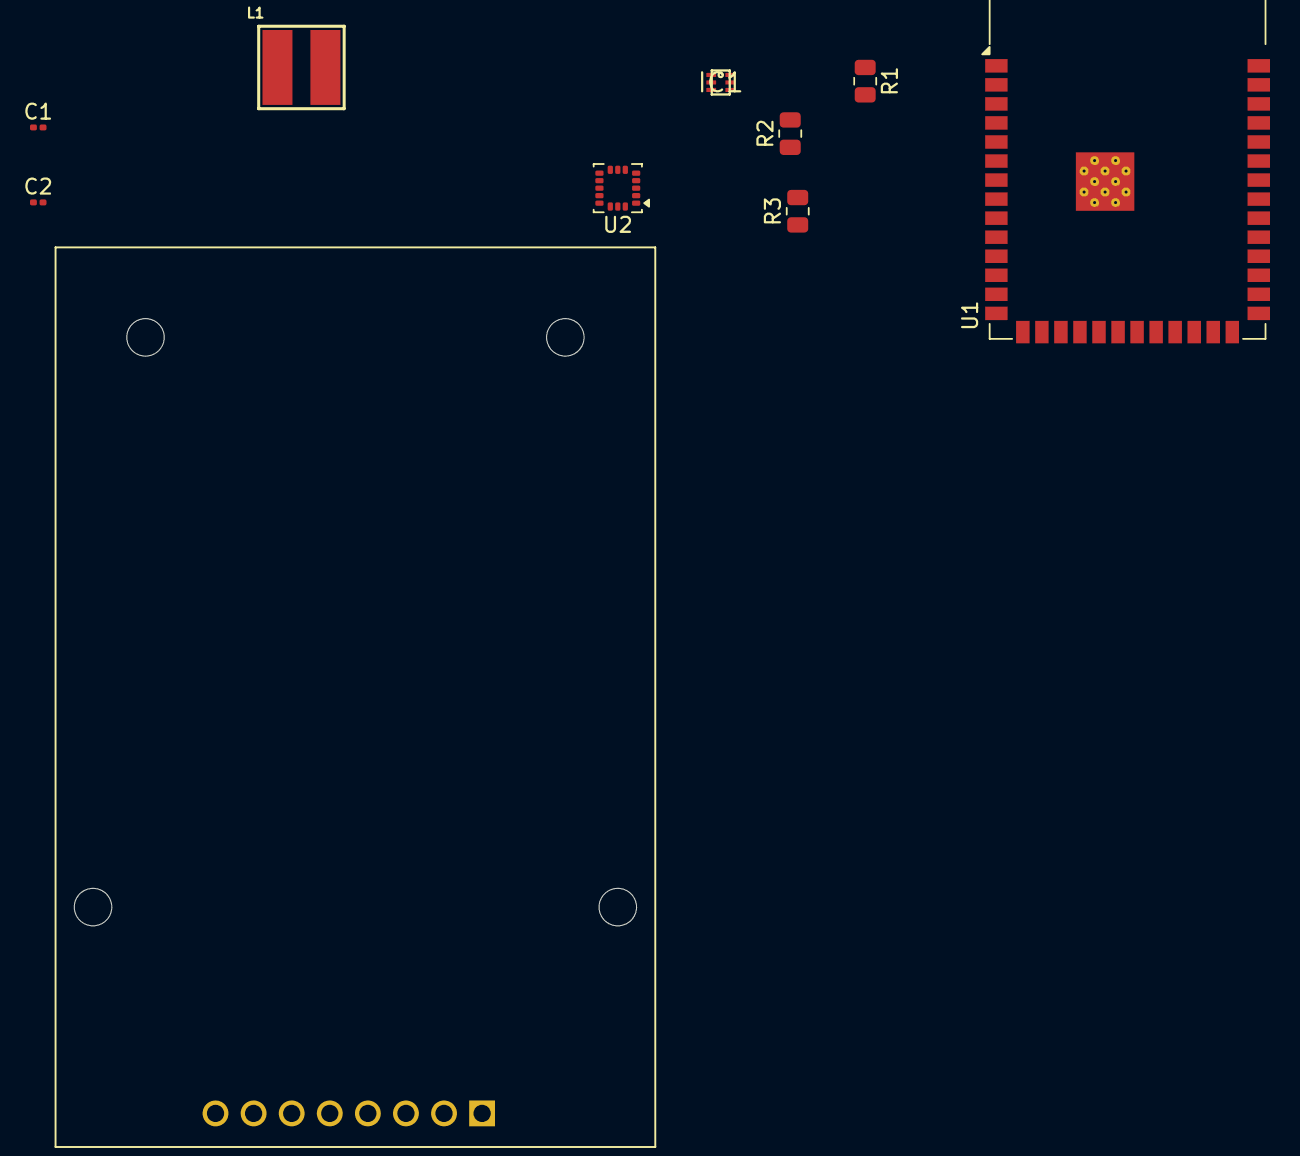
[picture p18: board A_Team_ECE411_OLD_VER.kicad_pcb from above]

Board: 2 copper layers, 10 parts (0 on the bottom side), 13 nets, no tracks yet.

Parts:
C1: 10u; C_0201_0603Metric
C2: 44u; C_0201_0603Metric
IC1: TPS61023_Boost_Converter; SOT563
L1: 1u; INDUCTOR_5X5MM_TDK_VLC5045
R1: 10k; R_0805_2012Metric
R2: 732k; R_0805_2012Metric
R3: 100k; R_0805_2012Metric
U1: ESP32-S3-WROOM-1
U2: LIS3DH_Accelerator; LGA-16_3x3mm_P0.5mm_LayoutBorder3x5y
U3: RF522_RFID; MODULE_CEG006900

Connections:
+5V: C2.1, IC1.6 (VOUT), R2.1
/IRQ: U1.21 (IO13), U3.4 (IRQ)
/MOSI: U1.19 (IO11), U3.6 (MOSI)
/SCK: U1.20 (IO12), U3.7 (SCK)
/SCL: U1.17 (IO9), U2.4 (SPC), U3.5 (MISO/SCL/TX)
/SDA: U1.12 (IO8), U2.6 (SDI), U3.8 (SS/SDA/RX)
GND: C1.2, C2.2, IC1.4 (GND), R3.2, U1.1 (GND), U1.40 (GND), U1.41 (GND), U2.5 (GND), U2.7 (SDO), U2.10 (GND), U2.12 (GND), U3.3 (GND)
unnamed: IC1.2 (EN), R1.1
unnamed: IC1.1 (FB), R2.2, R3.1
unnamed: IC1.5 (SW), L1.P$2 (2)
unnamed: C1.1, IC1.3 (VIN), L1.P$1 (1), U1.2 (3V3), U2.1 (VDD_IO), U2.14 (VDD), U3.1 (VCC)
unnamed: R1.2, U1.3 (EN)
unnamed: U1.27 (IO0), U3.2 (RST)

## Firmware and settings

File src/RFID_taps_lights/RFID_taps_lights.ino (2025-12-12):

#include <SPI.h>
#include <Adafruit_LIS3DH.h>
#include <Adafruit_Sensor.h>
#include <MFRC522v2.h>
#include <MFRC522DriverSPI.h>
#include <MFRC522DriverPinSimple.h>
#include <Adafruit_NeoPixel.h>

// --- Pin assignments ---
#define LIS3DH_CS 9
#define RFID_CS   10
#define RFID_RST  22
#define LED_FRONT 5   // front NeoPixel data pin
//#define LED_REAR  11  // breadboard rear LED (future use)
#define LED_REAR 6 //Protoboard GPIOpin
#define FRONT_LEDS 5
#define REAR_LEDS 5
#define LOCK_PIN  4   // lock / test pin
#define BUTTZER   11  // buzzer pin

// --- SPI bus pins (ESP32-S3 remap) ---
#define SPI_SCK   36
#define SPI_MISO  37
#define SPI_MOSI  35

//Accelerometer logic
const float FORWARD_THRESH     = 0.5;        // m/s^2: > this = "moving forward"
const float BRAKE_THRESH       = -0.5;       // m/s^2: < this = "braking / slowing"
const unsigned long REAR_BLINK_INTERVAL = 1000;   // ms
const unsigned long BRAKE_HOLD_MS       = 2000;  // ms

// --- ARMED shake / alarm tuning ---
const float CHAOS_DELTA_THRESH            = 3.0;       // m/s^2 per axis → "chaotic shake"
const unsigned long CHAOS_TIME_MS   = 3000;     // 5 s continuous chaos to trigger alarm
const unsigned long ALARM_DURATION_MS = 30000;   // 30 s alarm duration
const unsigned long BUZZ_TOGGLE_MS  = 300;       // beep on/off toggle during alarm

bool inChaos      = false;        // ARMED: currently seeing chaotic motion
unsigned long chaosStart = 0;     // when chaotic motion started

bool alarmActive  = false;        // ARMED: alarm is currently sounding
unsigned long alarmEnd   = 0;     // millis when alarm should stop

bool buzzerOn     = false;        // for alarm toggling
unsigned long lastBuzzToggle = 0; // last toggle time


// DISARMED brightness levels
const uint8_t RIDE_BRIGHTNESS = 200;   // while biking (forward accel)
const uint8_t BRAKE_BRIGHTNESS = 255;  // brake / stopped, full brightness


// --- Devices ---
Adafruit_LIS3DH lis = Adafruit_LIS3DH(LIS3DH_CS);

// NeoPixel strip: all 10 pixels driven from LED_FRONT
Adafruit_NeoPixel frontStrip(FRONT_LEDS, LED_FRONT, NEO_GRB + NEO_KHZ800);
Adafruit_NeoPixel rearStrip(REAR_LEDS, LED_REAR, NEO_GRB + NEO_KHZ800);

// MFRC522 RFID reader
MFRC522DriverPinSimple ss_pin(RFID_CS);
MFRC522DriverSPI       driver(ss_pin);
MFRC522                mfrc522(driver);

// Known UID (master card)
byte masterTagUID[] = {0xB1, 0x3F, 0x6B, 0xA2};

// Boolean logic
bool direction;      // accelerometer logic (future)
bool isLocked = true;
bool armed    = false;  // global ARMED state
bool lightsEnabled = false; // bike-light logic active only in DISARMED

// Baseline acceleration for ARMED mode (accounting for gravity)
float baseAx = 0.0;
float baseAy = 0.0;
float baseAz = 0.0;
bool  baseAccelValid = false;

// ---------- Helpers ----------

// Compare UID helper
bool compareUID(byte* uid1, byte* uid2, byte size) {
  for (byte i = 0; i < size; i++) {
    if (uid1[i] != uid2[i]) return false;
  }
  return true;
}

// Buzzer: wrong UID
void beepError() {
  tone(BUTTZER, 1000, 500);  // 2 kHz for 500 ms
  delay(500);
  noTone(BUTTZER);
}

// Single status LED: front strip, pixel 0
void setStatusLED(uint8_t r, uint8_t g, uint8_t b) {
  frontStrip.setPixelColor(0, frontStrip.Color(r, g, b));
  frontStrip.show();
}

// All front pixels
void setFrontStripColor(uint8_t r, uint8_t g, uint8_t b) {
  for (int i = 0; i < FRONT_LEDS; i++) {
    frontStrip.setPixelColor(i, frontStrip.Color(r, g, b));
  }
  frontStrip.show();
}

// All rear pixels
void setRearStripColor(uint8_t r, uint8_t g, uint8_t b) {
  for (int i = 0; i < REAR_LEDS; i++) {
    rearStrip.setPixelColor(i, rearStrip.Color(r, g, b));
  }
  rearStrip.show();
}

void clearAllLights() {
  // Turn off all front + rear pixels
  setFrontStripColor(0, 0, 0);
  setRearStripColor(0, 0, 0);
}


// 4s timer for 1 tap (DISARMED) or 2+ taps (ARMED)
void selectArmingMode() {
  uint8_t tapCount = 0;
  unsigned long start  = millis();
  const unsigned long window = 4000; // 4 seconds

  Serial.println("ARMED/DISARMED window open (4s). Tap master card now.");
  Serial.println("  - 1 tap = DISARMED (purple front strip)");
  Serial.println("  - 2+ taps = ARMED (red front strip)");

  while (millis() - start < window) {
    // Look for a new card
    if (!mfrc522.PICC_IsNewCardPresent()) {
      continue;  // no new card, keep waiting
    }
    if (!mfrc522.PICC_ReadCardSerial()) {
      continue;  // saw something but couldn't read
    }

    byte uidSize = mfrc522.uid.size;
    byte* uid    = mfrc522.uid.uidByte;

    // Is it the master tag?
    if (compareUID(uid, masterTagUID, uidSize)) {
      tapCount++;
      Serial.print("Master card tap #");
      Serial.println(tapCount);

      // simple debounce so one long hold doesn't count as multiple taps
      delay(300);

      //TODO: Decide if we want to keep this or not
      // Optional quick visual feedback on each tap
      setFrontStripColor(0, 0, 50);   // faint blue blink
      delay(150);
      setFrontStripColor(0, 0, 0);

      // Halt card
      mfrc522.PICC_HaltA();
      mfrc522.PCD_StopCrypto1();
    } else {
      // ignore strangers during arming window
      Serial.println("Non-master badge during arming window (ignored).");
      mfrc522.PICC_HaltA();
      mfrc522.PCD_StopCrypto1();
    }
  }

  // Decide mode based on tapCount
  if (tapCount == 0) {
    Serial.println("No taps detected. Keeping previous ARMED/DISARMED state.");
    return;  // leave 'armed' and LED colors as-is
  } else if (tapCount == 1) {
    armed = false;  // DISARMED
    lightsEnabled = true;
    Serial.println("DISARMED selected (1 tap). Front LEDs = purple.");
   
    //DISARMED purple LEDs. Stays lit for 1s
    setFrontStripColor(128, 0, 128);  // purple 
    delay(1000);
    setFrontStripColor(0, 0, 0);
    setRearStripColor(0, 0, 0);
  } else { // 2 or more taps => ARMED with all red LEDs
    armed = true;
    lightsEnabled = false;
    Serial.println("ARMED selected (2+ taps). Disabling bike-light motion logic for now.");
    
    //setting ARMED state LED colors
    setFrontStripColor(255, 0, 0);    // red
    delay(1000);
    setFrontStripColor(0, 0, 0); //Turn off LEDS

    // Take baseline acceleration (including gravity) at the moment of arming
  sensors_event_t event;
  lis.getEvent(&event);
  baseAx = event.acceleration.x;
  baseAy = event.acceleration.y;
  baseAz = event.acceleration.z;
  baseAccelValid = true;

  Serial.print("ARMED baseline set: ax=");
  Serial.print(baseAx);
  Serial.print(" ay=");
  Serial.print(baseAy);
  Serial.print(" az=");
  Serial.println(baseAz);
  }
}

// Scale RGB by brightness (0–255)
uint32_t scaleColor(Adafruit_NeoPixel &strip, uint8_t r, uint8_t g, uint8_t b, uint8_t brightness) {
  uint16_t scaledR = (r * brightness) / 255;
  uint16_t scaledG = (g * brightness) / 255;
  uint16_t scaledB = (b * brightness) / 255;
  return strip.Color(scaledR, scaledG, scaledB);
}

void setFrontScaled(uint8_t r, uint8_t g, uint8_t b, uint8_t brightness) {
  for (int i = 0; i < FRONT_LEDS; i++) {
    frontStrip.setPixelColor(i, scaleColor(frontStrip, r, g, b, brightness));
  }
  frontStrip.show();
}

void setRearScaled(uint8_t r, uint8_t g, uint8_t b, uint8_t brightness) {
  for (int i = 0; i < REAR_LEDS; i++) {
    rearStrip.setPixelColor(i, scaleColor(rearStrip, r, g, b, brightness));
  }
  rearStrip.show();
}


// ---------- Motion-based light logic ----------
void updateMotionLights() {
  // Only run bike-light motion logic when in DISARMED mode
  if (!lightsEnabled || armed) {
    return;  // do nothing; whatever static colors we set stay as-is
  }

  static unsigned long lastBlink = 0;
  static bool rearOn = false;
  static unsigned long brakeUntil = 0;

  sensors_event_t event;
  lis.getEvent(&event);

  float ax = event.acceleration.x;  // m/s^2 along X
  unsigned long now = millis();

  // FORWARD / ACCELERATING
  if (ax > FORWARD_THRESH) {
    // Cancel any brake hold
    brakeUntil = 0;

    // Front: solid white
      setFrontScaled(255, 255, 255, RIDE_BRIGHTNESS);

    // REAR: blinking red at 200 brightness
    if (now - lastBlink >= REAR_BLINK_INTERVAL) {
      rearOn = !rearOn;
      if (rearOn) setRearScaled(255, 0, 0, RIDE_BRIGHTNESS);
      else        setRearScaled(0,   0, 0, 0);
      lastBlink = now;
    }

    return;

  }

  // BRAKING / SLOWING DOWN (negative accel)
  if (ax < BRAKE_THRESH) {
    // If this is the first time we notice a brake, start the hold window
    if (brakeUntil == 0) {
      brakeUntil = now + BRAKE_HOLD_MS;
      Serial.println("[DISARMED] Brake detected, switching to full brightness.");
    }

    // FRONT: white at full 255
    setFrontScaled(255, 255, 255, BRAKE_BRIGHTNESS);

    // REAR: solid red at full 255
    setRearScaled(255, 0, 0, BRAKE_BRIGHTNESS);

    return;
  }

// --- IDLE / COASTING ---
  // treat this like braking (bike is stopped = brake light)
  setFrontScaled(255, 255, 255, BRAKE_BRIGHTNESS);
  setRearScaled(255, 0, 0, BRAKE_BRIGHTNESS);
}

// ---------- ARMED shake-detection + alarm logic ----------
void updateArmedAlarm() {
  // Only care when ARMED
  if (!armed) {
    return;
  }

  unsigned long now = millis();

  // If alarm is currently active, keep running it for ALARM_DURATION_MS
  if (alarmActive) {
    if (now >= alarmEnd) {
      // Stop alarm
      Serial.println("[ARMED] Alarm duration ended, stopping buzzer.");
      alarmActive = false;
      noTone(BUTTZER);
      buzzerOn = false;
      return;
    }

    // Run repeating buzzer pattern (non-blocking)
    if (now - lastBuzzToggle >= BUZZ_TOGGLE_MS) {
      buzzerOn = !buzzerOn;
      if (buzzerOn) {
        tone(BUTTZER, 2500);  // alarm tone
      } else {
        noTone(BUTTZER);
      }
      lastBuzzToggle = now;
    }

    return;  // don't check new motion while screaming
  }

  // If we reach here, ARMED but no active alarm yet.
  // Check accelerometer to see if we are in "chaotic" motion (change from baseline).
  if (!baseAccelValid) {
    // Shouldn't happen, but just in case:
    Serial.println("[ARMED] Warning: baseline accel not valid; skipping chaos check.");
    return;
  }

  sensors_event_t event;
  lis.getEvent(&event);
  float ax = event.acceleration.x;
  float ay = event.acceleration.y;
  float az = event.acceleration.z;

  // Delta from baseline (removes static gravity at arming orientation)
  float dax = ax - baseAx;
  float day = ay - baseAy;
  float daz = az - baseAz;

  float dMag = sqrtf(dax*dax + day*day + daz*daz);
  Serial.print("[ARMED] dMag=");
  Serial.print(dMag, 2);
  Serial.print(" (threshold ");
  Serial.print(CHAOS_DELTA_THRESH, 2);
  Serial.println(")");

  bool chaotic = (dMag > CHAOS_DELTA_THRESH);

  if (chaotic) {
    if (!inChaos) {
      // Just entered chaotic region
      inChaos = true;
      chaosStart = now;
      Serial.println("[ARMED] Chaotic movement detected! Starting 10s chaos timer...");
    } else {
      // Already in chaos; check if time exceeded threshold
      unsigned long elapsed = now - chaosStart;
      if (elapsed >= CHAOS_TIME_MS) {
        Serial.println("[ARMED] Chaotic movement sustained for 10s. TRIGGERING ALARM!");
        alarmActive = true;
        alarmEnd = now + ALARM_DURATION_MS;

        // Start buzzer immediately
        buzzerOn = true;
        tone(BUTTZER, 2500);
        lastBuzzToggle = now;
      } else {
        Serial.print("[ARMED] Chaotic movement ongoing: ");
        Serial.print(elapsed / 1000.0, 1);
        Serial.println(" s (need 10 s to alarm).");
      }
    }
  } else {
    // Not chaotic right now
    if (inChaos) {
      // We were in chaos but it stopped before timer expired
      unsigned long elapsed = now - chaosStart;
      Serial.print("[ARMED] Chaotic movement STOPPED after ");
      Serial.print(elapsed / 1000.0, 1);
      Serial.println(" s (<10 s) → treating as harmless jostle; resetting timer.");
      inChaos = false;
      chaosStart = 0;
    }
  }
}




// ---------- SETUP ----------

void setup() {
  Serial.begin(115200);
  // while (!Serial);  // optional; can comment out if it hangs

  Serial.println("\nInitializing SPI and devices...");

  // SPI on custom pins
  SPI.begin(SPI_SCK, SPI_MISO, SPI_MOSI);

  // NeoPixel setup
  frontStrip.begin();
  rearStrip.begin();
  frontStrip.setBrightness(80); // 0–255
  rearStrip.setBrightness(80);
  frontStrip.show();            // all off
  rearStrip.show();             //all off

  // Lock + buzzer pins
  pinMode(LOCK_PIN, OUTPUT);
  digitalWrite(LOCK_PIN, HIGH); // locked initially
  pinMode(BUTTZER, OUTPUT);

  // LIS3DH
  if (!lis.begin(LIS3DH_CS)) {
    Serial.println("Could not find LIS3DH. Check wiring!");
    while (1) {
      delay(10);
    }
  }
  lis.setRange(LIS3DH_RANGE_2_G);
  Serial.println("LIS3DH initialized.");

  // RC522
  mfrc522.PCD_Init();
  Serial.println("RC522 initialized.");
  Serial.println("Ready! -- Scan card, plz.");

  // Optional: little startup blink + beep
  setStatusLED(0, 0, 50);
  beepError();
  setStatusLED(0, 0, 0);
}

// ---------- LOOP ----------

void loop() {
  updateMotionLights(); //DISARMED state
  updateArmedAlarm(); // ARMED state

  // Wait for a card
  if (!mfrc522.PICC_IsNewCardPresent()) return;
  if (!mfrc522.PICC_ReadCardSerial())   return;

  byte uidSize = mfrc522.uid.size;
  byte* uid    = mfrc522.uid.uidByte;

  Serial.print("Scanned UID: ");
  for (byte i = 0; i < uidSize; i++) {
    if (uid[i] < 0x10) Serial.print("0");
    Serial.print(uid[i], HEX);
    Serial.print(" ");
  }
  Serial.println();

  if (compareUID(uid, masterTagUID, uidSize)) {
  // Correct badge: always reset visual state first
  Serial.println("Your card is detected");

    if (alarmActive) {
    Serial.println("[RFID] Clearing active alarm and silencing buzzer.");
    alarmActive = false;
    inChaos = false;
    chaosStart = 0;
    noTone(BUTTZER);
    buzzerOn = false;
  }

  // Always reset visual state first
  Serial.println("Resetting LED state and unlocking...");

  clearAllLights();

  // Show "OK" status on front LED 0 (green)
  setStatusLED(0, 255, 0);  // first pixel green
  delay(500);
  setStatusLED(0, 0, 0);    // turn that pixel off again

  // Lock / unlock logic
  digitalWrite(LOCK_PIN, LOW);   // unlock
  delay(3000);
  digitalWrite(LOCK_PIN, HIGH);  // lock
  Serial.println("Locked again.");

  // Halt current card before arming mode
  mfrc522.PICC_HaltA();
  mfrc522.PCD_StopCrypto1();

  // 4) 4s arming/disarming selection window
  selectArmingMode();
}


  else {
    // Wrong badge
    Serial.println("Who is this? Denied!! Stranger Danger!");
    setStatusLED(255, 0, 0);  // first pixel red
    delay(500);
    setStatusLED(0, 0, 0);
    beepError();

    // Halt this card too
    mfrc522.PICC_HaltA();
    mfrc522.PCD_StopCrypto1();
  }

  // After this, loop() returns and waits for next card
}

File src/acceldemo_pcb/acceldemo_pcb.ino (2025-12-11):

// Basic demo for accelerometer readings from Adafruit LIS3DH

#include <Wire.h>
#include <SPI.h>
#include <Adafruit_LIS3DH.h>
#include <Adafruit_Sensor.h>
#include <Adafruit_NeoPixel.h> // Include the Adafruit library

// Used for software SPI
#define SPI_SCK   36
#define SPI_MISO  37
#define SPI_MOSI  35
// Used for hardware & software SPI
#define LIS3DH_CS 9

// neopixel pin and globals
#define PIN_FRONT A1      // headlight
#define PIN_BACK A2       //tail light
#define NUM_LEDS 5 // Number of LEDs on the strip

// software SPI
//Adafruit_LIS3DH lis = Adafruit_LIS3DH(LIS3DH_CS, LIS3DH_MOSI, LIS3DH_MISO, LIS3DH_CLK);
// hardware SPI
Adafruit_LIS3DH lis = Adafruit_LIS3DH(LIS3DH_CS);
// Low Power 5Khz data rate needs faster SPI, and calling setPerformanceMode & setDataRate
//Adafruit_LIS3DH lis = Adafruit_LIS3DH(LIS3DH_CS, 2000000);
// I2C
//Adafruit_LIS3DH lis = Adafruit_LIS3DH();

//neopixel strip info
Adafruit_NeoPixel front_strip = Adafruit_NeoPixel(NUM_LEDS, PIN_FRONT, NEO_GRB + NEO_KHZ800); //headlights
Adafruit_NeoPixel back_strip = Adafruit_NeoPixel(NUM_LEDS, PIN_BACK, NEO_GRB + NEO_KHZ800); //taillights

void setup(void) {
  Serial.begin(115200);
  while (!Serial) delay(10);     // will pause Zero, Leonardo, etc until serial console opens

  Serial.println("LIS3DH test!");

  Serial.println("\nInitializing SPI devices...");
  SPI.begin(SPI_SCK, SPI_MISO, SPI_MOSI);  // custom SPI pins
  
  if (! lis.begin(0x18)) {   // change this to 0x19 for alternative i2c address
    Serial.println("Couldnt start");
    while (1) yield();
  }
  Serial.println("LIS3DH found!");

  // lis.setRange(LIS3DH_RANGE_4_G);   // 2, 4, 8 or 16 G!

  Serial.print("Range = "); Serial.print(2 << lis.getRange());
  Serial.println("G");

  // lis.setPerformanceMode(LIS3DH_MODE_LOW_POWER);
  Serial.print("Performance mode set to: ");
  switch (lis.getPerformanceMode()) {
    case LIS3DH_MODE_NORMAL: Serial.println("Normal 10bit"); break;
    case LIS3DH_MODE_LOW_POWER: Serial.println("Low Power 8bit"); break;
    case LIS3DH_MODE_HIGH_RESOLUTION: Serial.println("High Resolution 12bit"); break;
  }

  // lis.setDataRate(LIS3DH_DATARATE_50_HZ);
  Serial.print("Data rate set to: ");
  switch (lis.getDataRate()) {
    case LIS3DH_DATARATE_1_HZ: Serial.println("1 Hz"); break;
    case LIS3DH_DATARATE_10_HZ: Serial.println("10 Hz"); break;
    case LIS3DH_DATARATE_25_HZ: Serial.println("25 Hz"); break;
    case LIS3DH_DATARATE_50_HZ: Serial.println("50 Hz"); break;
    case LIS3DH_DATARATE_100_HZ: Serial.println("100 Hz"); break;
    case LIS3DH_DATARATE_200_HZ: Serial.println("200 Hz"); break;
    case LIS3DH_DATARATE_400_HZ: Serial.println("400 Hz"); break;

    case LIS3DH_DATARATE_POWERDOWN: Serial.println("Powered Down"); break;
    case LIS3DH_DATARATE_LOWPOWER_5KHZ: Serial.println("5 Khz Low Power"); break;
    case LIS3DH_DATARATE_LOWPOWER_1K6HZ: Serial.println("1.6 Khz Low Power"); break;
  }
}

void loop() {
  lis.read();      // get X Y and Z data at once
  // Then print out the raw data
  Serial.print("X:  "); Serial.print(lis.x);
  Serial.print("  \tY:  "); Serial.print(lis.y);
  Serial.print("  \tZ:  "); Serial.print(lis.z);

  /* Or....get a new sensor event, normalized */
  sensors_event_t event;
  lis.getEvent(&event);

  /* Display the results (acceleration is measured in m/s^2) */
  Serial.print("\t\tX: "); Serial.print(event.acceleration.x);
  Serial.print(" \tY: "); Serial.print(event.acceleration.y);
  Serial.print(" \tZ: "); Serial.print(event.acceleration.z);
  Serial.println(" m/s^2 ");

  Serial.println();

  delay(200);
}

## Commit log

2025-11-11 adding test hex print
2025-11-11 adding spreadsheet
    [411 Components List.xlsx]
2025-11-18 adding details for project
    [A_Team_ECE411.kicad_pcb]
2025-11-19 Add files via upload
    Here's the code I have to test proper connection the LIS3DH and the RFID to our ESP32s.
2025-11-19 Add files via upload
    Here's our most recent wiring diagram for our breadboard! Will update if/when things change.
2025-11-20 Create BOM
2025-11-20 Add files via upload
    updated wiring diagram to include our surface mount caps
2025-11-20 Add files via upload
    Most recent schematic and pcb files. The footprint for the accelerometer is the most urgent thing to be adjusted and then general cleanup could be helpful if time allows.
    [A_Team_ECE411.kicad_pcb, A_Team_ECE411.kicad_sch]
2025-11-21 adding iterations of Illuminoti board
    [A_Team_ECE411.kicad_pcb, A_Team_ECE411.kicad_sch, A_Team_ECE411_accel_bb.kicad_pcb]
2025-11-23 Add files via upload
    edited footprints, resolved DRC errors
    [A_Team_ECE411.kicad_pcb, A_Team_ECE411.kicad_sch]
2025-11-23 Add files via upload
    updated schematic pdf with edited symbols, resolved DRC errors
2025-11-23 Add files via upload
    gerber files for jcl pcb order
    [A_Team_ECE411-B_Cu.gbl, A_Team_ECE411-B_Mask.gbs, A_Team_ECE411-B_Silkscreen.gbo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]
2025-11-29 Add files via upload
    Here's a test code for the LEDs, code is fully commented for clarity. Let me know if you have any questions, or need any help testing! - Cass
2025-12-01 Add files via upload
    corrected headlight and taillight colors
    [lights_red_white.ino]
2025-12-06 flow diagram for final script RD
2025-12-11 correct healight and taillight colors
    headlights = white and tail lights = red
    [lights_setup.ino]
2025-12-11 added current integration, and subsystem test scripts for LEDs and accellerometer
2025-12-12 adding wire configs and components list
    [411 Components List.xlsx, Wiring Configuration.xlsx]
